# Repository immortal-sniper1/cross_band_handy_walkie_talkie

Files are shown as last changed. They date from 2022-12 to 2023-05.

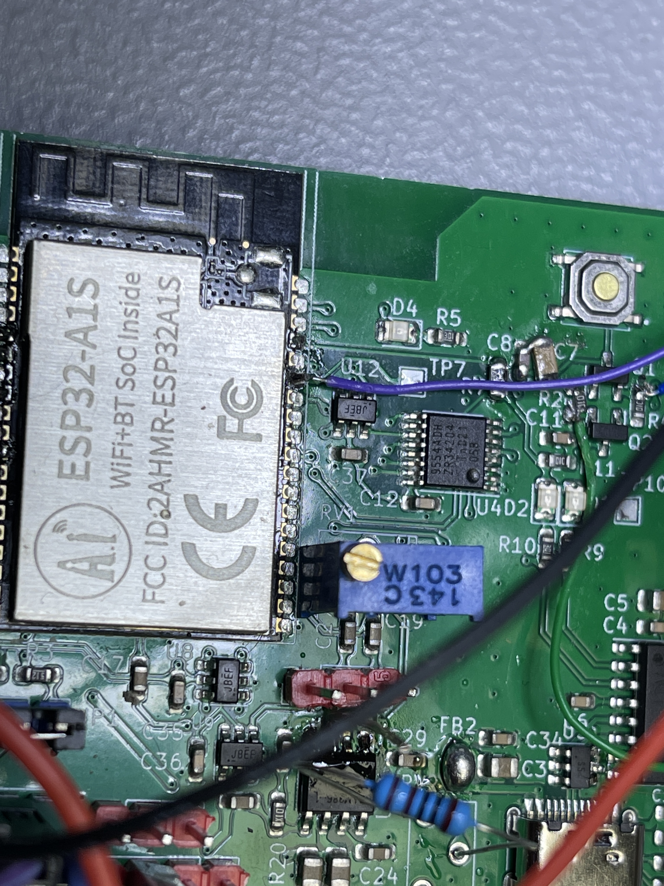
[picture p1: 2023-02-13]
Hardware/PICS/IMG_79081.JPG

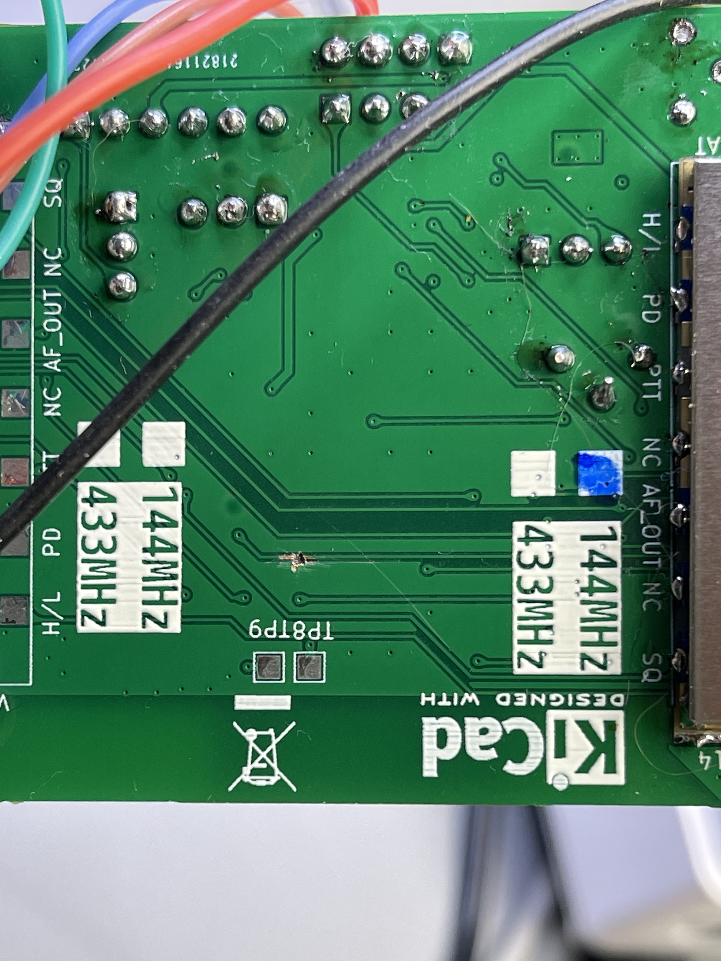
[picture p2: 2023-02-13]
Hardware/PICS/IMG_79101.JPG

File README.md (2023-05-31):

# Cross Band Handy Walkie Talkie

A Cross band handy walkie talkie: This HT would include 2 SA818s, one for 70cm and one for 2m and could be used for satellite work.
 
We recommend to install the following libraries:

__Audio__

- https://github.com/pschatzmann/arduino-audio-tools.git
- https://github.com/pschatzmann/arduino-audiokit.git (ES8388 driver for AudioKitStream class)
- https://github.com/thaaraak/es8388 (alternative ES8388 driver)
 
__DRA818__

To use the Transceiver you need an Arduino library. e.g.
- https://github.com/fatpat/arduino-dra818.git

 You can install this project as Arduino Library. To compile a Sketch select the __ESP32S3 Dev Module__ as board.

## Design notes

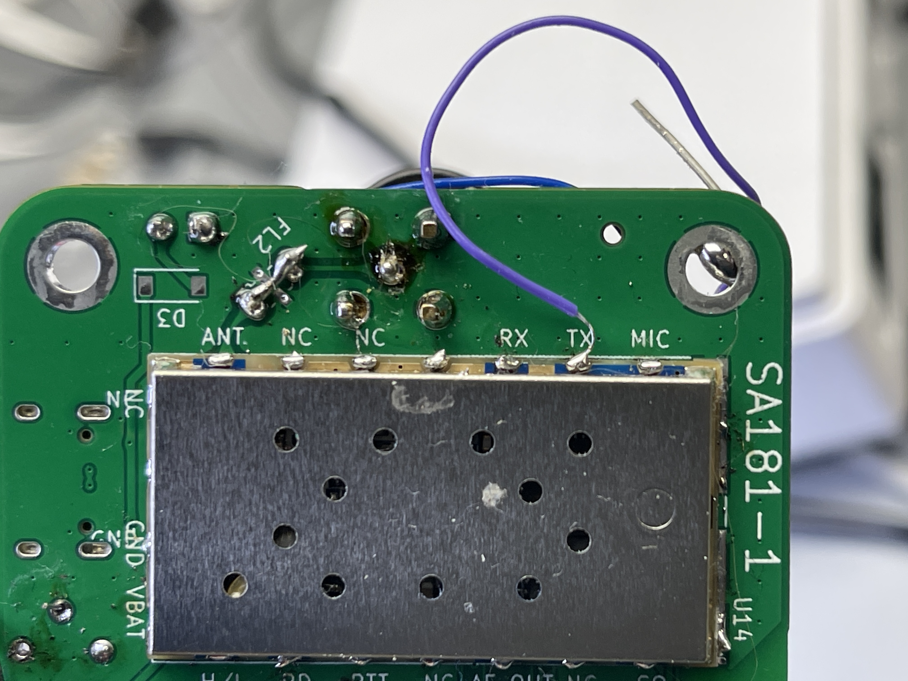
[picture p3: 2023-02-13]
Hardware/PICS/IMG_79091s.JPG

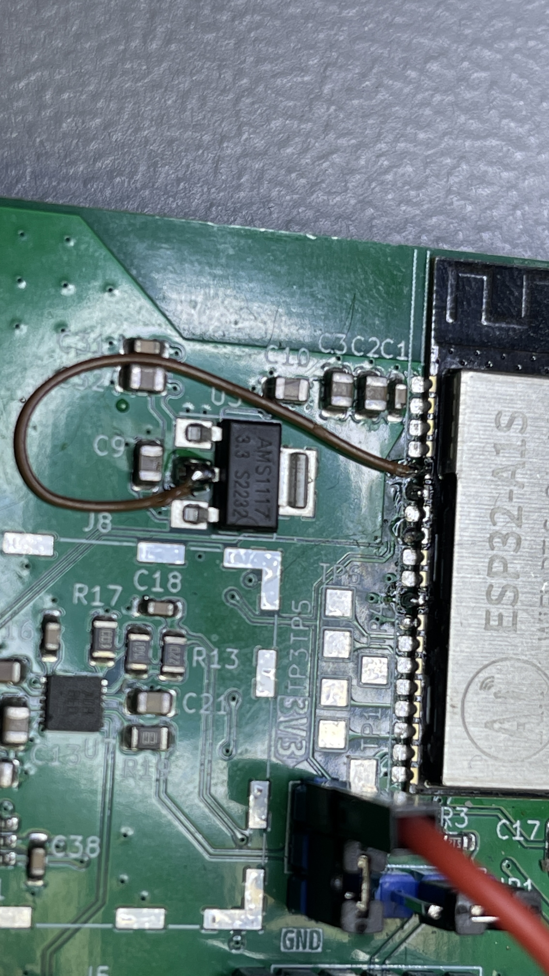
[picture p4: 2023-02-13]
Hardware/PICS/IMG_E79071.JPG

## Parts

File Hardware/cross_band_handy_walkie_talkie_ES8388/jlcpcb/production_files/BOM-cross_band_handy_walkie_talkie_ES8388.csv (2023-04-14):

Comment | Designator | Footprint | LCSC
FerriteBead_Small | FB1 | R_0805_2012Metric | C1015
AudioJack4_SwitchTR1 | J6 | PJ-316A-6A | C128987
100n | C1,C2 | C_0603_1608Metric_Pad1.08x0.95mm_HandSolder | C14663
AO3401A | Q2,Q3,Q4 | SOT-23 | C15127
4n7 | C27,C32 | C_0402_1005Metric | C1538
1u | C48,C55,C56,C8 | C_0603_1608Metric_Pad1.08x0.95mm_HandSolder | C15849
15p | C6 | C_0603_1608Metric_Pad1.08x0.95mm_HandSolder | C1644
1k | R15,R4,R5 | R_0805_2012Metric | C17513
1k | R38,R39,R44,R45 | R_0603_1608Metric | C21190
D_Schottky | D3 | D_SMA_Handsoldering | C22452
red | D4,D6,D7,D8 | LED_0603_1608Metric | C2286
1Meg | R7 | R_0603_1608Metric_Pad0.98x0.95mm_HandSolder | C22935
green | D1,D2,D5 | LED_0805_2012Metric | C2297
10 | R10,R11,R12,R13,R21,R24,R25,R47,R48,R49,R50,R8,R9 | R_0402_1005Metric | C25077
27 | R26,R27,R28,R29 | R_0402_1005Metric | C25092
0R1 | R16,R43 | R_1206_3216Metric | C25334
10k | R14,R17,R18,R19,R20,R36,R40,R46,R52,R53 | R_0402_1005Metric | C25744
10k | R1,R30,R31,R37,R42,R51,R6 | R_0603_1608Metric_Pad0.98x0.95mm_HandSolder | C25804
2k2 | R32,R33,R34,R35,R41 | R_0402_1005Metric | C25879
5k1 | R2,R22,R23,R3 | R_0402_1005Metric | C25905
SA818S | U7,U8 | SA818S | C3001549
MCU_RESET | SW1,SW2 | PTS526SK15SMTR2LFS | C318884
USB_C_Receptacle | J1 | USB_C_Receptacle_HRO_TYPE-C-31-M-12 | C319148
10k | RV1,RV2,RV3,RV4 | Potentiometer_Bourns_3314J_Vertical | C36376
ES8388 | U5 | QFN-28-1EP_4x4mm_P0.45mm_EP2.4x2.4mm_ThermalVias | C365736
22u | C24,C26,C28,C30,C33,C36,C63 | C_0805_2012Metric | C45783
TP5000 | U4 | QFN-16-1EP_4x4mm_P0.65mm_EP2.5x2.5mm_ThermalVias | C51699
1u | C13,C17,C20,C23,C34,C35,C37,C38,C40,C42,C43,C45,C46,C5,C51,C53 | C_0402_1005Metric | C52923
Micro_SD_Card_Det | J2 | microSD_HC_Molex_104031-0811 | C585350
4u7 | L1,L2,L3,L4 | Inductor_2.5x2x1.2mm | C602016
AMS1117-3.3 | U3 | SOT-223-3_TabPin2 | C6186
TPA2012D2 | U6 | QFN-20-1EP_4x4mm_P0.5mm_EP2.6x2.6mm_ThermalVias | C7717
SRV05-4 | U1 | SOT-23-6 | C85364
nMOS | Q1,Q5,Q6 | SOT-23 | C8545
10u | C10,C11,C12,C14,C15,C16,C18,C19,C21,C22,C25,C29,C3,C31,C39,C4,C41,C44,C47,C50,C52,C54,C57,C58,C59,C60,C61,C62,C7,C9 | C_0603_1608Metric | C96446
Screw_Terminal_01x02 | J5 | Altech_AK300_1x02_P5.00mm_45-Degree
SMA | J7 | SMA_Amphenol_901-144_Vertical
SMA | J8 | SMA_Amphenol_901-144_Vertical
Screw_Terminal_01x02 | J3 | Altech_AK300_1x02_P5.00mm_45-Degree
LFCN-160 | FL2 | Filter_Mini-Circuits_FV1206
LFCN-160 | FL1 | Filter_Mini-Circuits_FV1206

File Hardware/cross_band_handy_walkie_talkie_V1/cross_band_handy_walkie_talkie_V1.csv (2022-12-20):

Id | Designator | Package | Quantity | Designation | Supplier and ref
1 | J5,J3,J2,J4 | PinHeader_1x03_P2.54mm_Vertical | 4 | Conn_01x03
2 | C7 | C_0603_1608Metric_Pad1.08x0.95mm_HandSolder | 1 | DNP
3 | C10,C3,C5,C33,C32,C2,C26,C13,C14,C9,C25 | C_0805_2012Metric | 11 | 10u
4 | RV1,RV2 | Potentiometer_Bourns_3266W_Vertical | 2 | 10k
5 | R2,R4,R11 | R_0603_1608Metric_Pad0.98x0.95mm_HandSolder | 3 | 10k
6 | C29 | C_0603_1608Metric_Pad1.08x0.95mm_HandSolder | 1 | 1u-10u?
7 | C28,C20,C27,C19,C17,C24 | C_0603_1608Metric_Pad1.08x0.95mm_HandSolder | 6 | 1u
8 | R10,R9,R5 | R_0603_1608Metric_Pad0.98x0.95mm_HandSolder | 3 | 300
9 | C4,C38,C6,C18,C11,C12,C16,C34,C31,C1,C37,C35,C36 | C_0603_1608Metric_Pad1.08x0.95mm_HandSolder | 13 | 100n
10 | U11,U8,U9,U12 | SOT-23-6 | 4 | TS5A63157DBV
11 | J7 | PinHeader_1x04_P2.54mm_Vertical | 1 | Conn_01x04
12 | D4,D1,D2 | LED_0805_2012Metric | 3 | LED_Small
13 | R1,R3,R14,R12 | R_0603_1608Metric_Pad0.98x0.95mm_HandSolder | 4 | 5k1
14 | U4 | TSSOP-16_4.4x5mm_P0.65mm | 1 | PCA9554APW
15 | SW1 | PTS526SK15SMTR2LFS | 1 | MCU_RESET
16 | R20 | R_0603_1608Metric_Pad0.98x0.95mm_HandSolder | 1 | 10
17 | U2 | ESP32-A1S | 1 | ESP32-A1S
18 | U3 | SOT-223-3_TabPin2 | 1 | AMS1117-3.3
19 | R17 | R_0805_2012Metric | 1 | 100k
20 | J15,J14 | SMA_Amphenol_901-144_Vertical | 2 | SMA
21 | C21 | C_0805_2012Metric | 1 | 470n
22 | Q1,Q2 | SOT-23 | 2 | MMBT3904
23 | C30 | C_0603_1608Metric_Pad1.08x0.95mm_HandSolder | 1 | 47n
24 | U10 | SOIC-8-1EP_3.9x4.9mm_P1.27mm_EP2.41x3.3mm_ThermalVias | 1 | LM386
25 | R15 | R_0805_2012Metric | 1 | 150k
26 | C15 | C_0603_1608Metric_Pad1.08x0.95mm_HandSolder | 1 | 10p
27 | C22 | C_0805_2012Metric | 1 | 2u2
28 | L1 | L_0805_2012Metric | 1 | L_Small
29 | J1 | PinHeader_1x06_P2.54mm_Vertical | 1 | Conn_01x06
30 | U1 | SOIC-16_3.9x9.9mm_P1.27mm | 1 | CH340C
31 | JP1 | PinHeader_1x03_P2.54mm_Vertical | 1 | Jumper_3_Bridged12
32 | R19 | R_0805_2012Metric | 1 | 1k
33 | FB2 | R_0805_2012Metric_Pad1.20x1.40mm_HandSolder | 1 | MH2029-401Y
34 | J9 | PinHeader_1x02_P2.54mm_Vertical | 1 | Conn_01x02
35 | R16,R7 | R_0603_1608Metric_Pad0.98x0.95mm_HandSolder | 2 | 1Meg
36 | C8 | C_0603_1608Metric_Pad1.08x0.95mm_HandSolder | 1 | 15n
37 | R13 | R_0805_2012Metric | 1 | 2k2
38 | J6 | USB_C_Receptacle_HRO_TYPE-C-31-M-12 | 1 | USB_C_Receptacle
39 | U7 | DFN-14-1EP_3x3mm_P0.4mm_EP1.78x2.35mm | 1 | MAX9814
40 | FL2,FL1 | Filter_Mini-Circuits_FV1206 | 2 | LFCN-160
41 | D3 | D_SOD-123 | 1 | D_Small
42 | U14,U13 | SA818S | 2 | SA818S

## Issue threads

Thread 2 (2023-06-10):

Status

pschatzmann, 2023-06-10:
Since you did not open the discussion tab, I create an issue instead to document the current status:

All my test cases were passing except the audio input via the earphones which has a lot of noise
- output
- output via amplifier
- SD
- SDMMC

On my board I do not have the SA818s soldered so I can't really do any tests with this. But just for the documentation could you describe how the output and input is connected to the ES8388: I would assume that they are on AUDIO_HAL_ADC_INPUT_LINE2 and AUDIO_HAL_DAC_OUTPUT_LINE2 ?

immortal-sniper1, 2023-06-10:
1 i dont know how do open discussions
2 regarding noise i am not sure and we need to talk with Andreas , maybe another cap type heavier via stitching or a pre amplifier for larger input impedance .
3 Yes they are supposed to be connected there. The modules can receive analogue audio and output it too and there are a few pins that control this functionality
As a note on the modules even if we had them it would be only a receiver or a sender so in a way the RF tests need to be done by Andreas since he has most boards and can also ask x y z for a transmission on those bands. Theoretically we can also receive audio but it is going to be more like catch what u can.

pschatzmann, 2023-06-10:
Activating discussions is easy: Just click on the settings tab and activate the Discussions flag

immortal-sniper1, 2023-06-10:
try now , should be open.
BTW was the speed for the SPI and the codec appropriate ?
did u use SPI 1bit or 4bit for the SD card ?

pschatzmann, 2023-06-10:
If I remember right, SDMMC was working only with 4 bits but not with 1 bit. At least that't the version that you find in the [example](https://github.com/immortal-sniper1/cross_band_handy_walkie_talkie/blob/master/examples/test-sdmmc/test-sdmmc.ino)

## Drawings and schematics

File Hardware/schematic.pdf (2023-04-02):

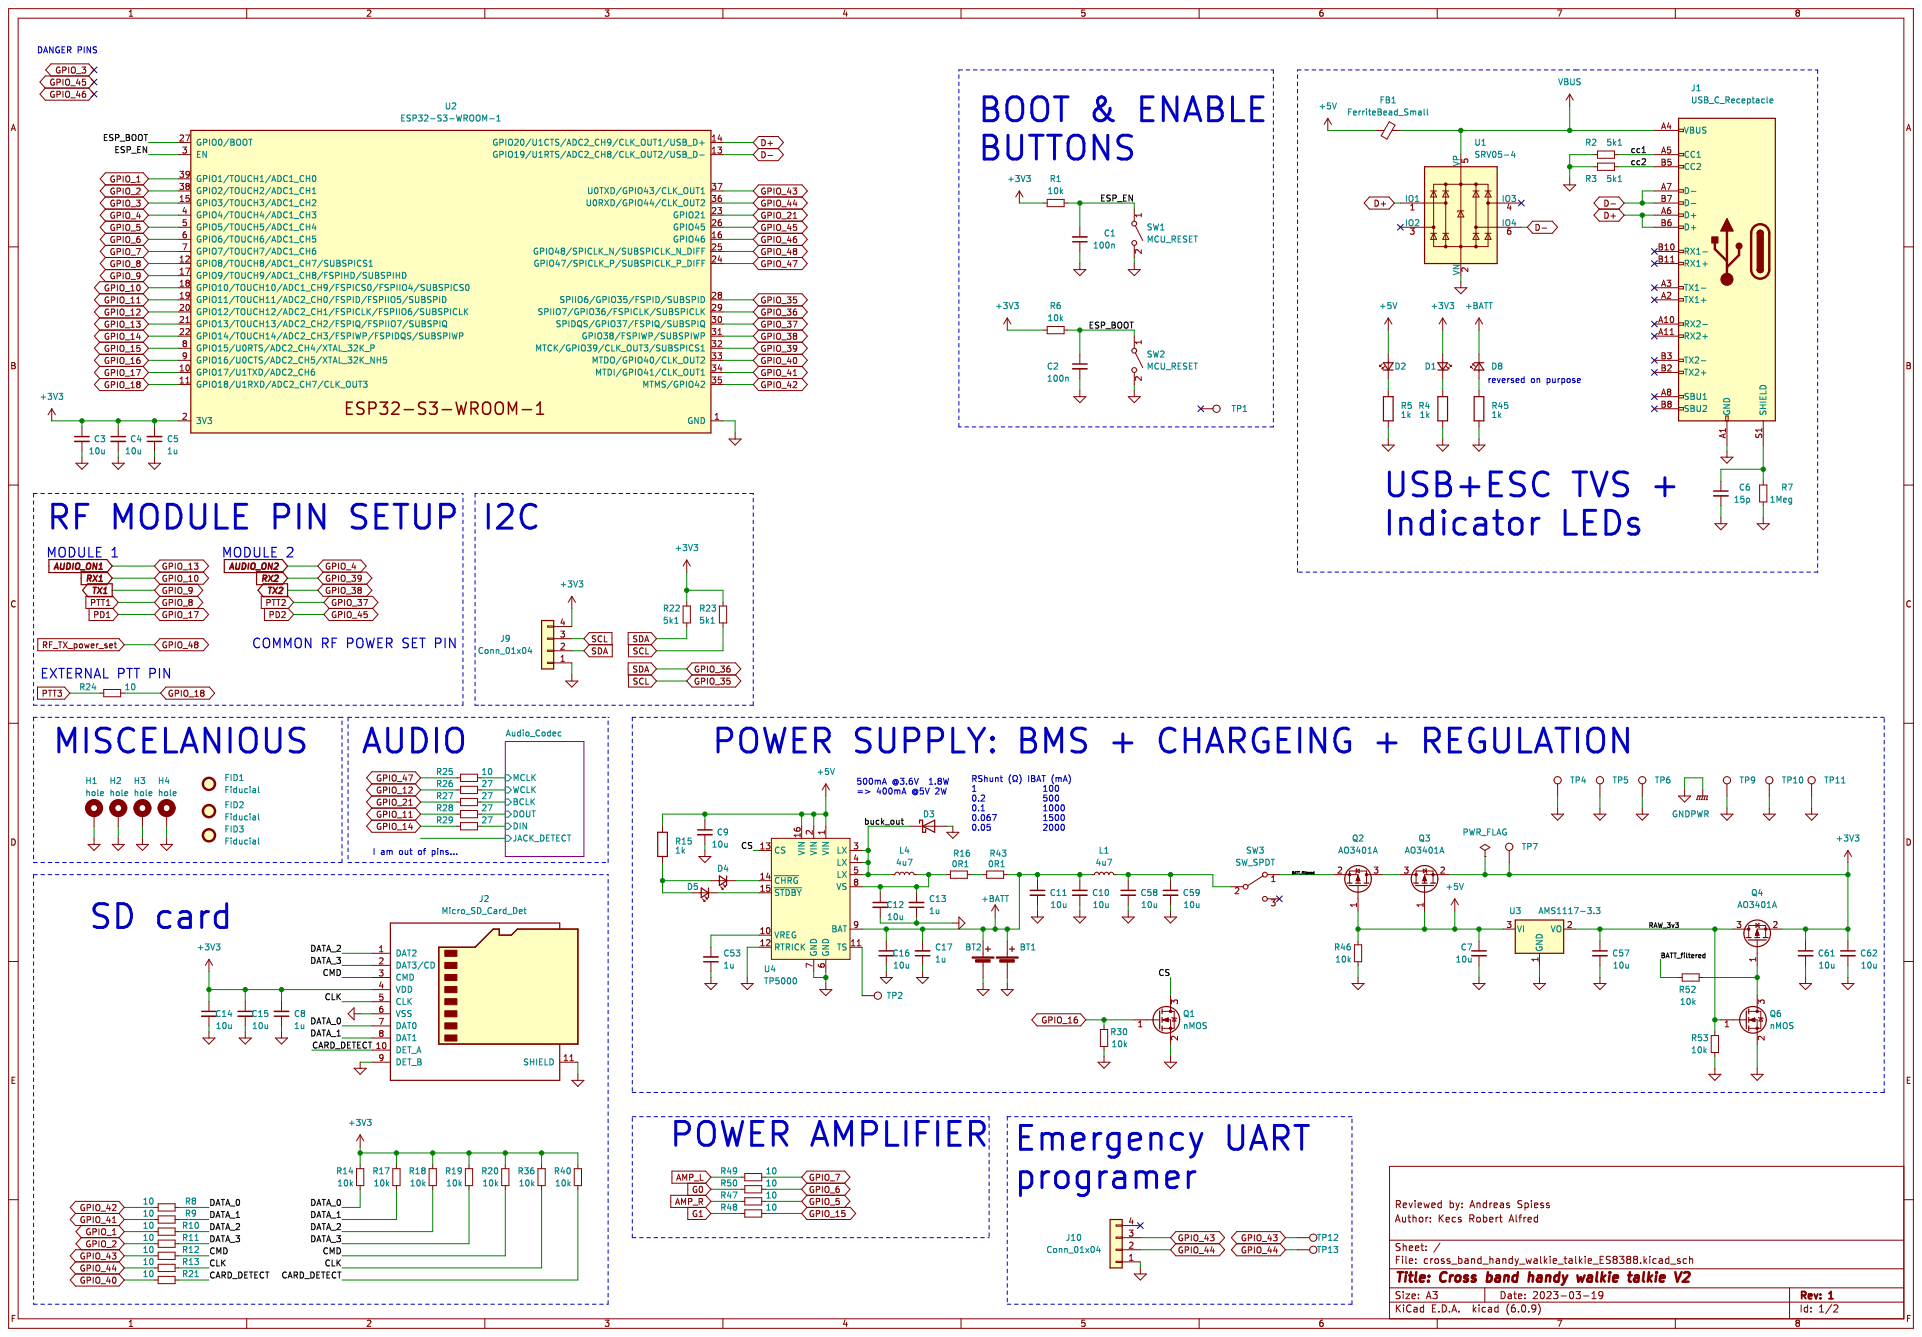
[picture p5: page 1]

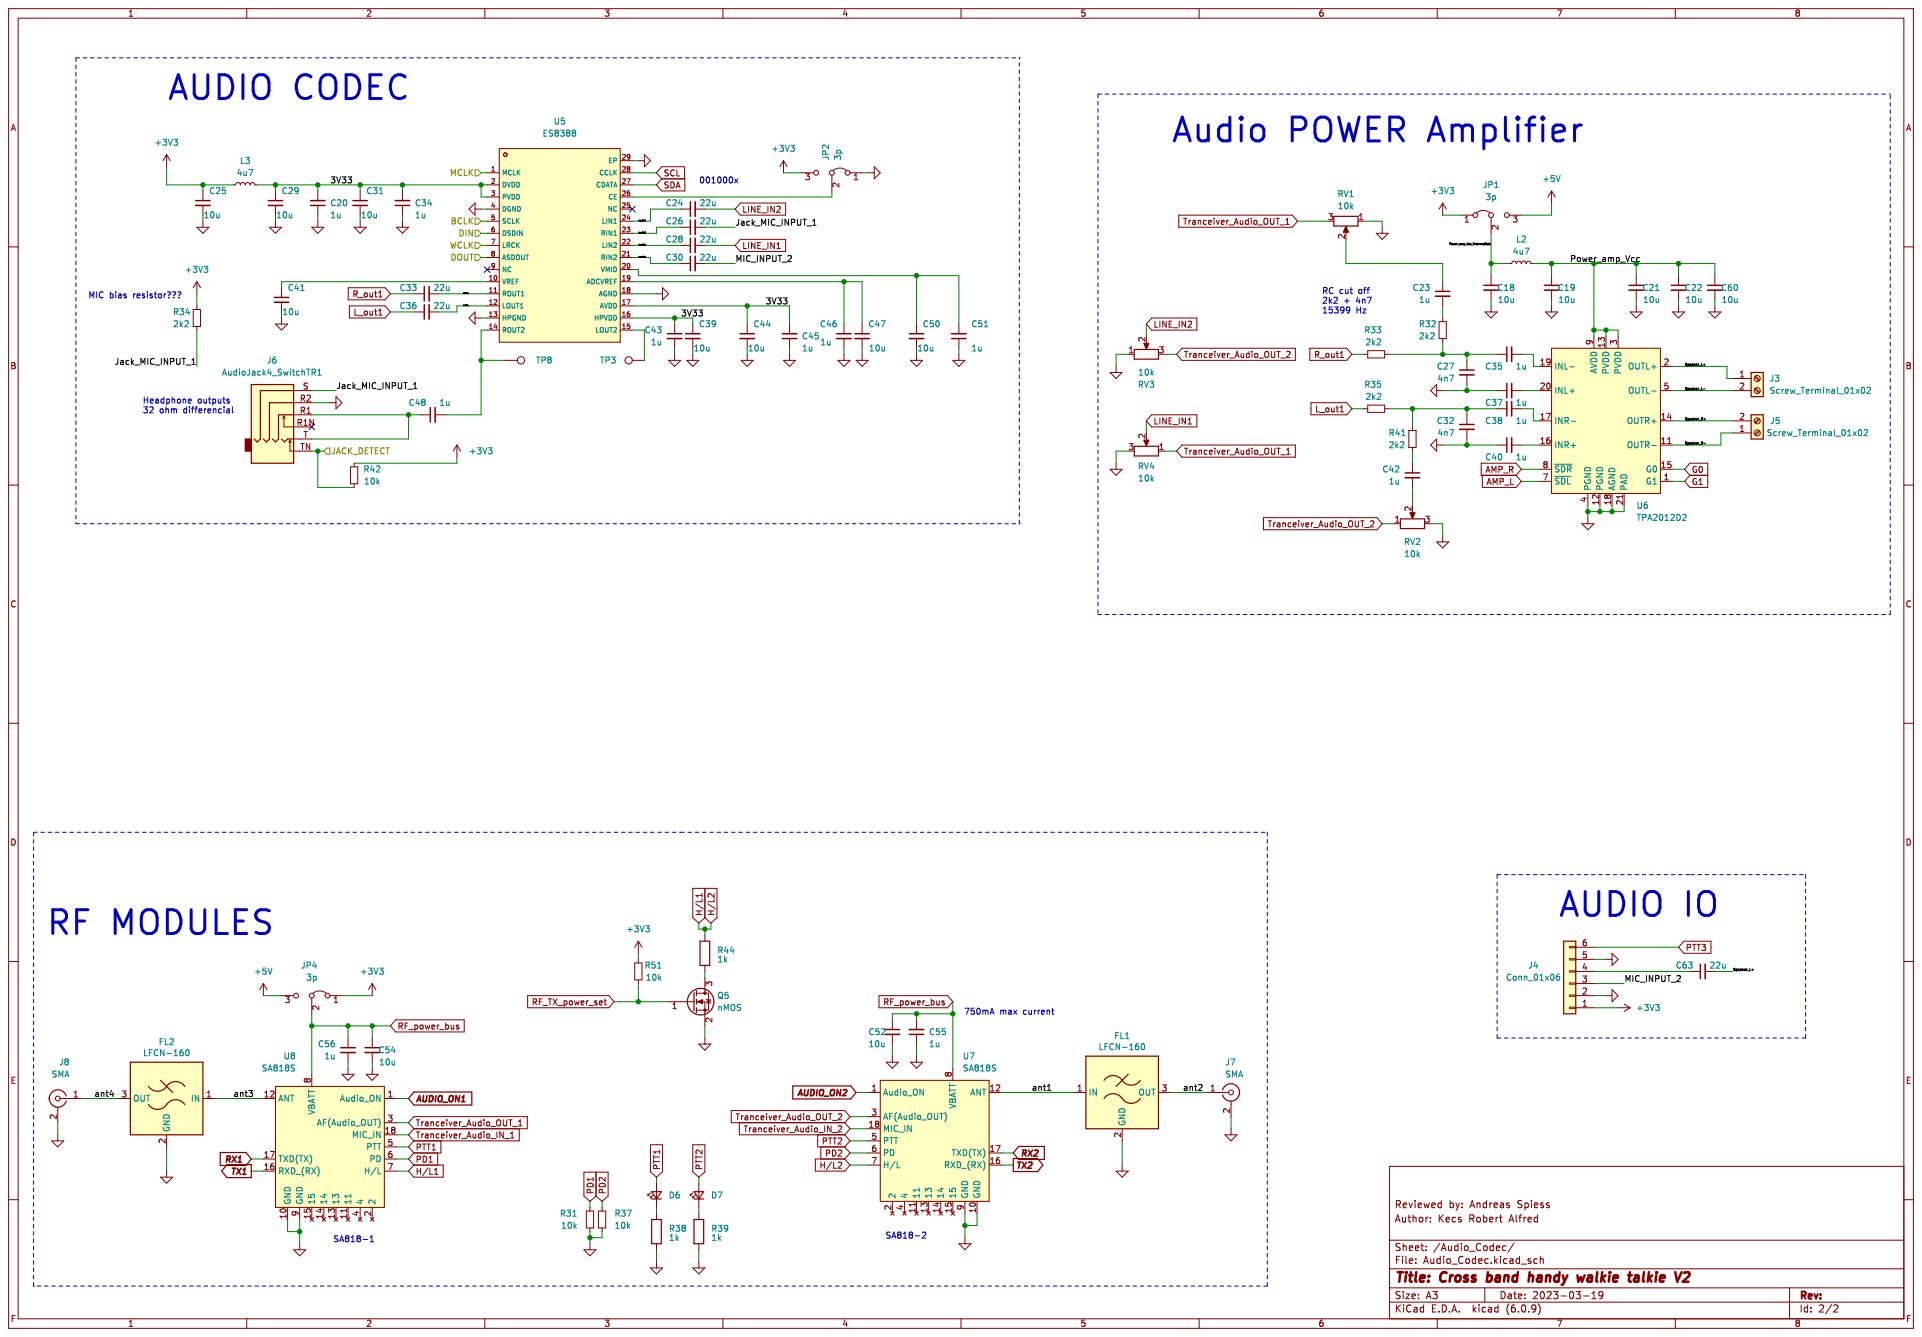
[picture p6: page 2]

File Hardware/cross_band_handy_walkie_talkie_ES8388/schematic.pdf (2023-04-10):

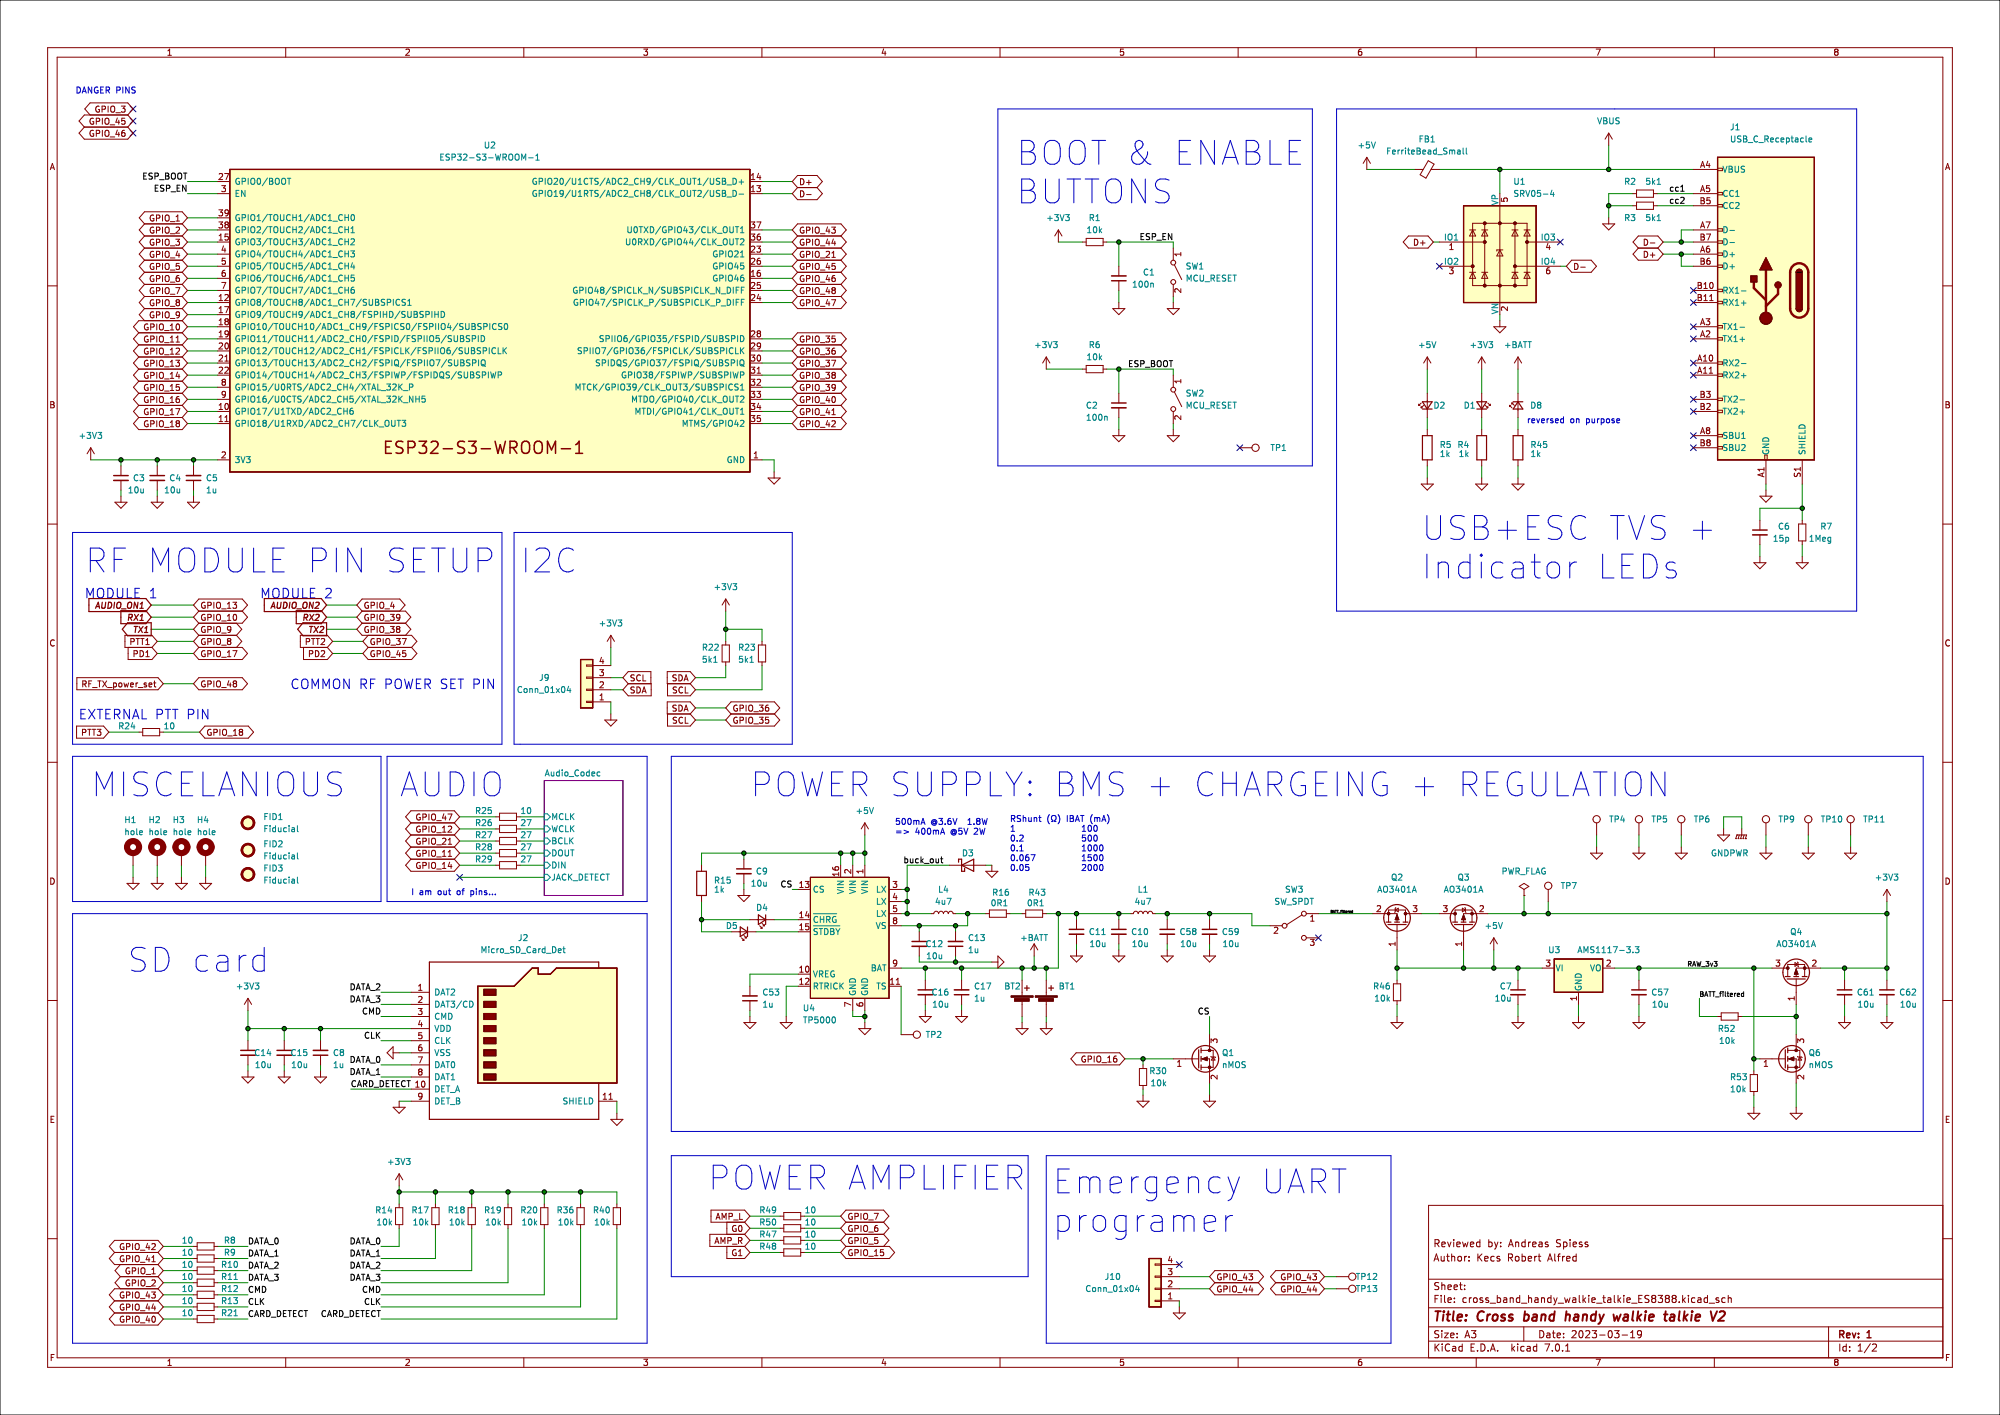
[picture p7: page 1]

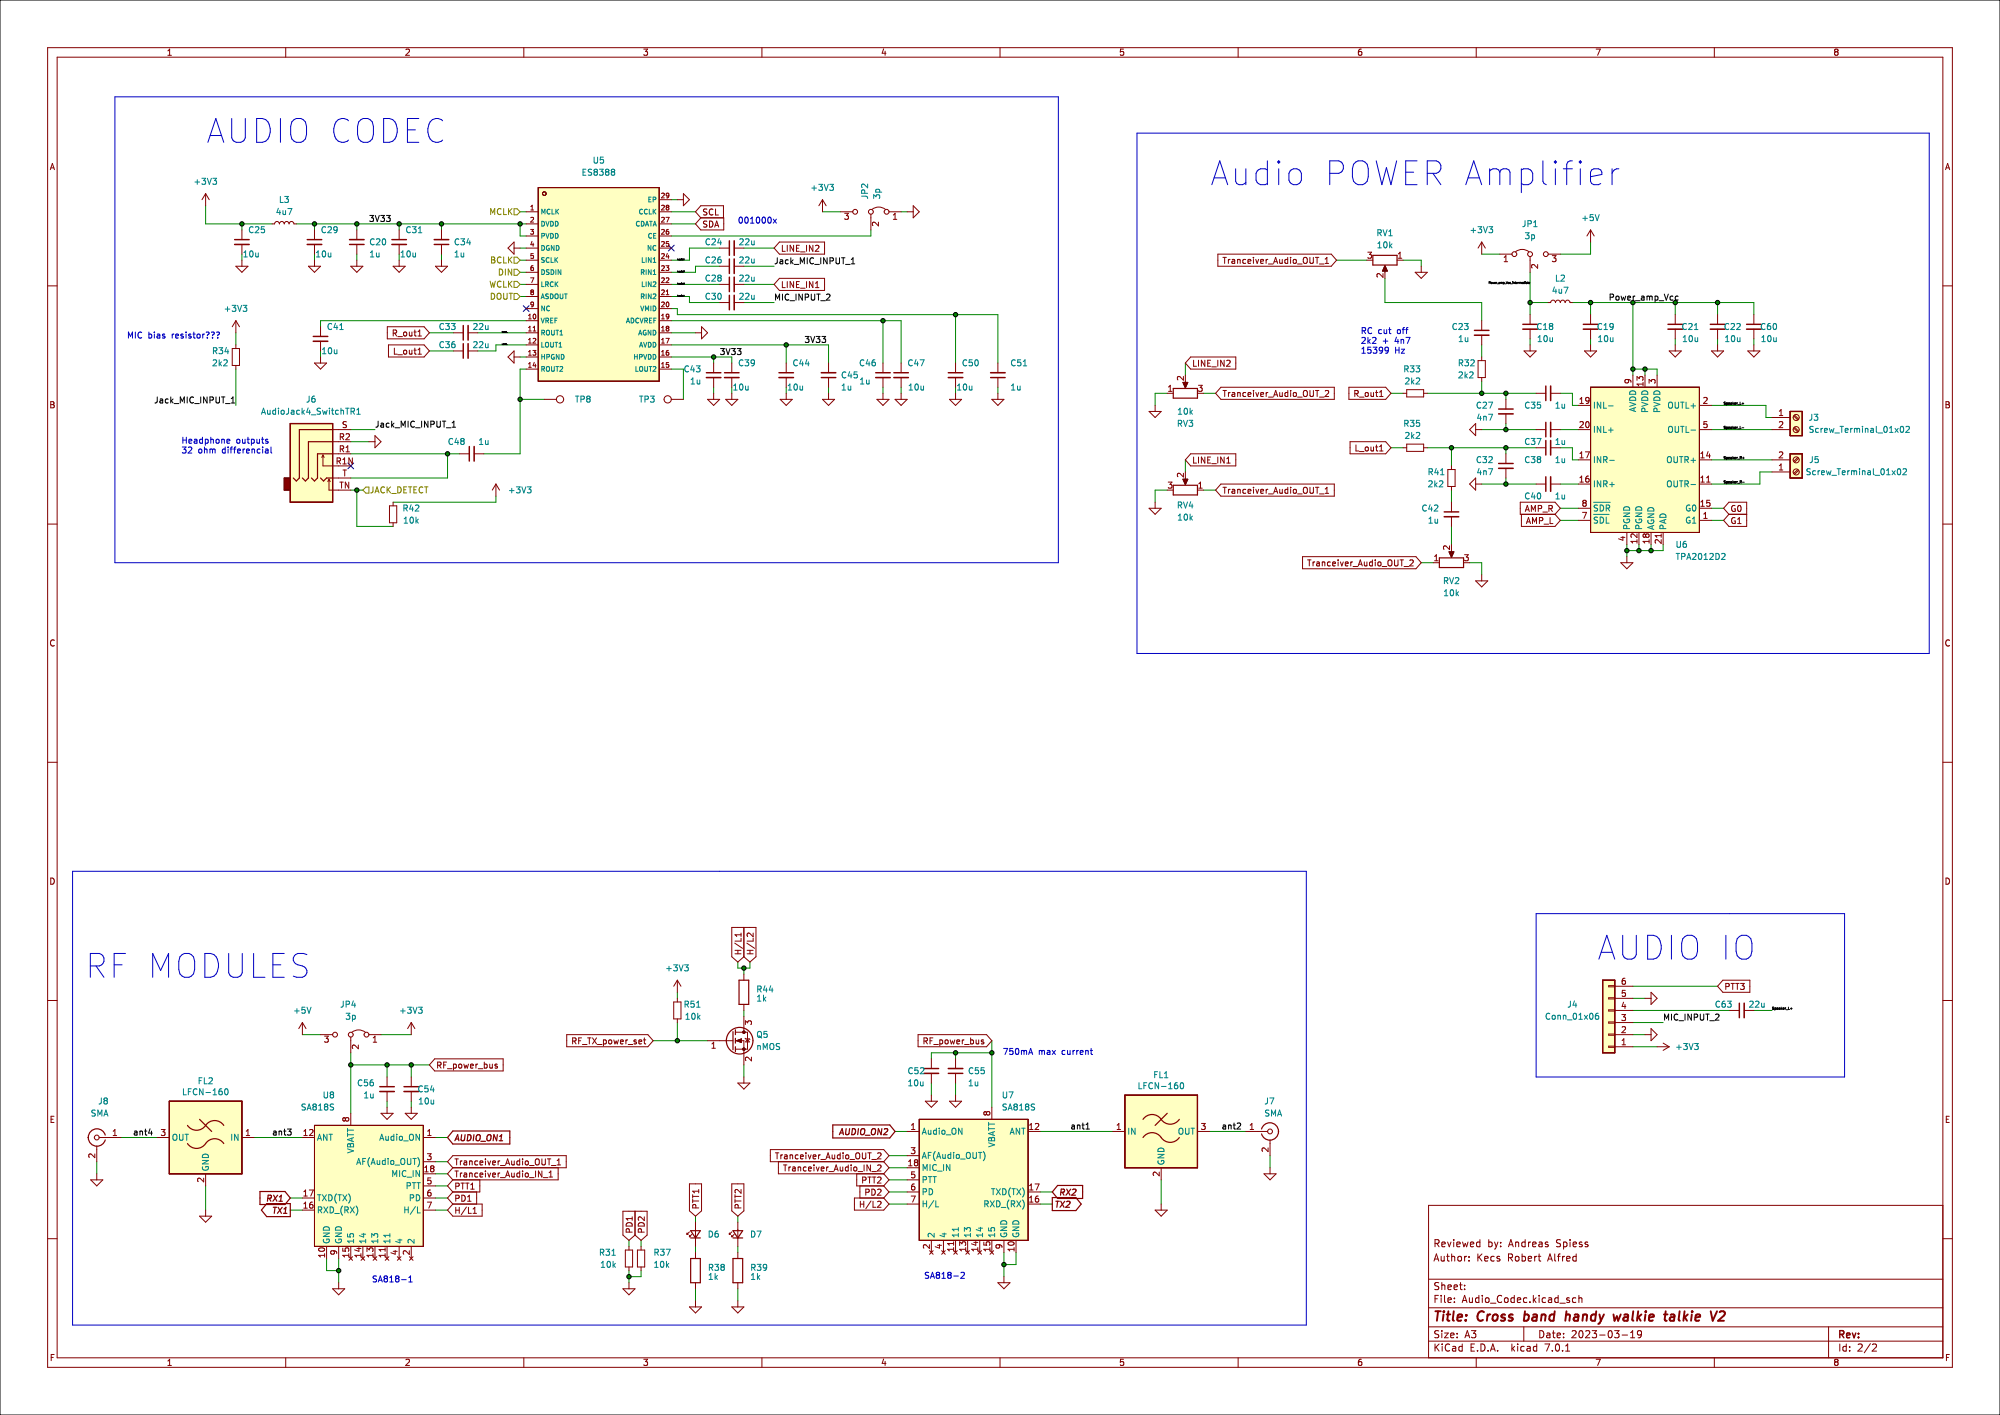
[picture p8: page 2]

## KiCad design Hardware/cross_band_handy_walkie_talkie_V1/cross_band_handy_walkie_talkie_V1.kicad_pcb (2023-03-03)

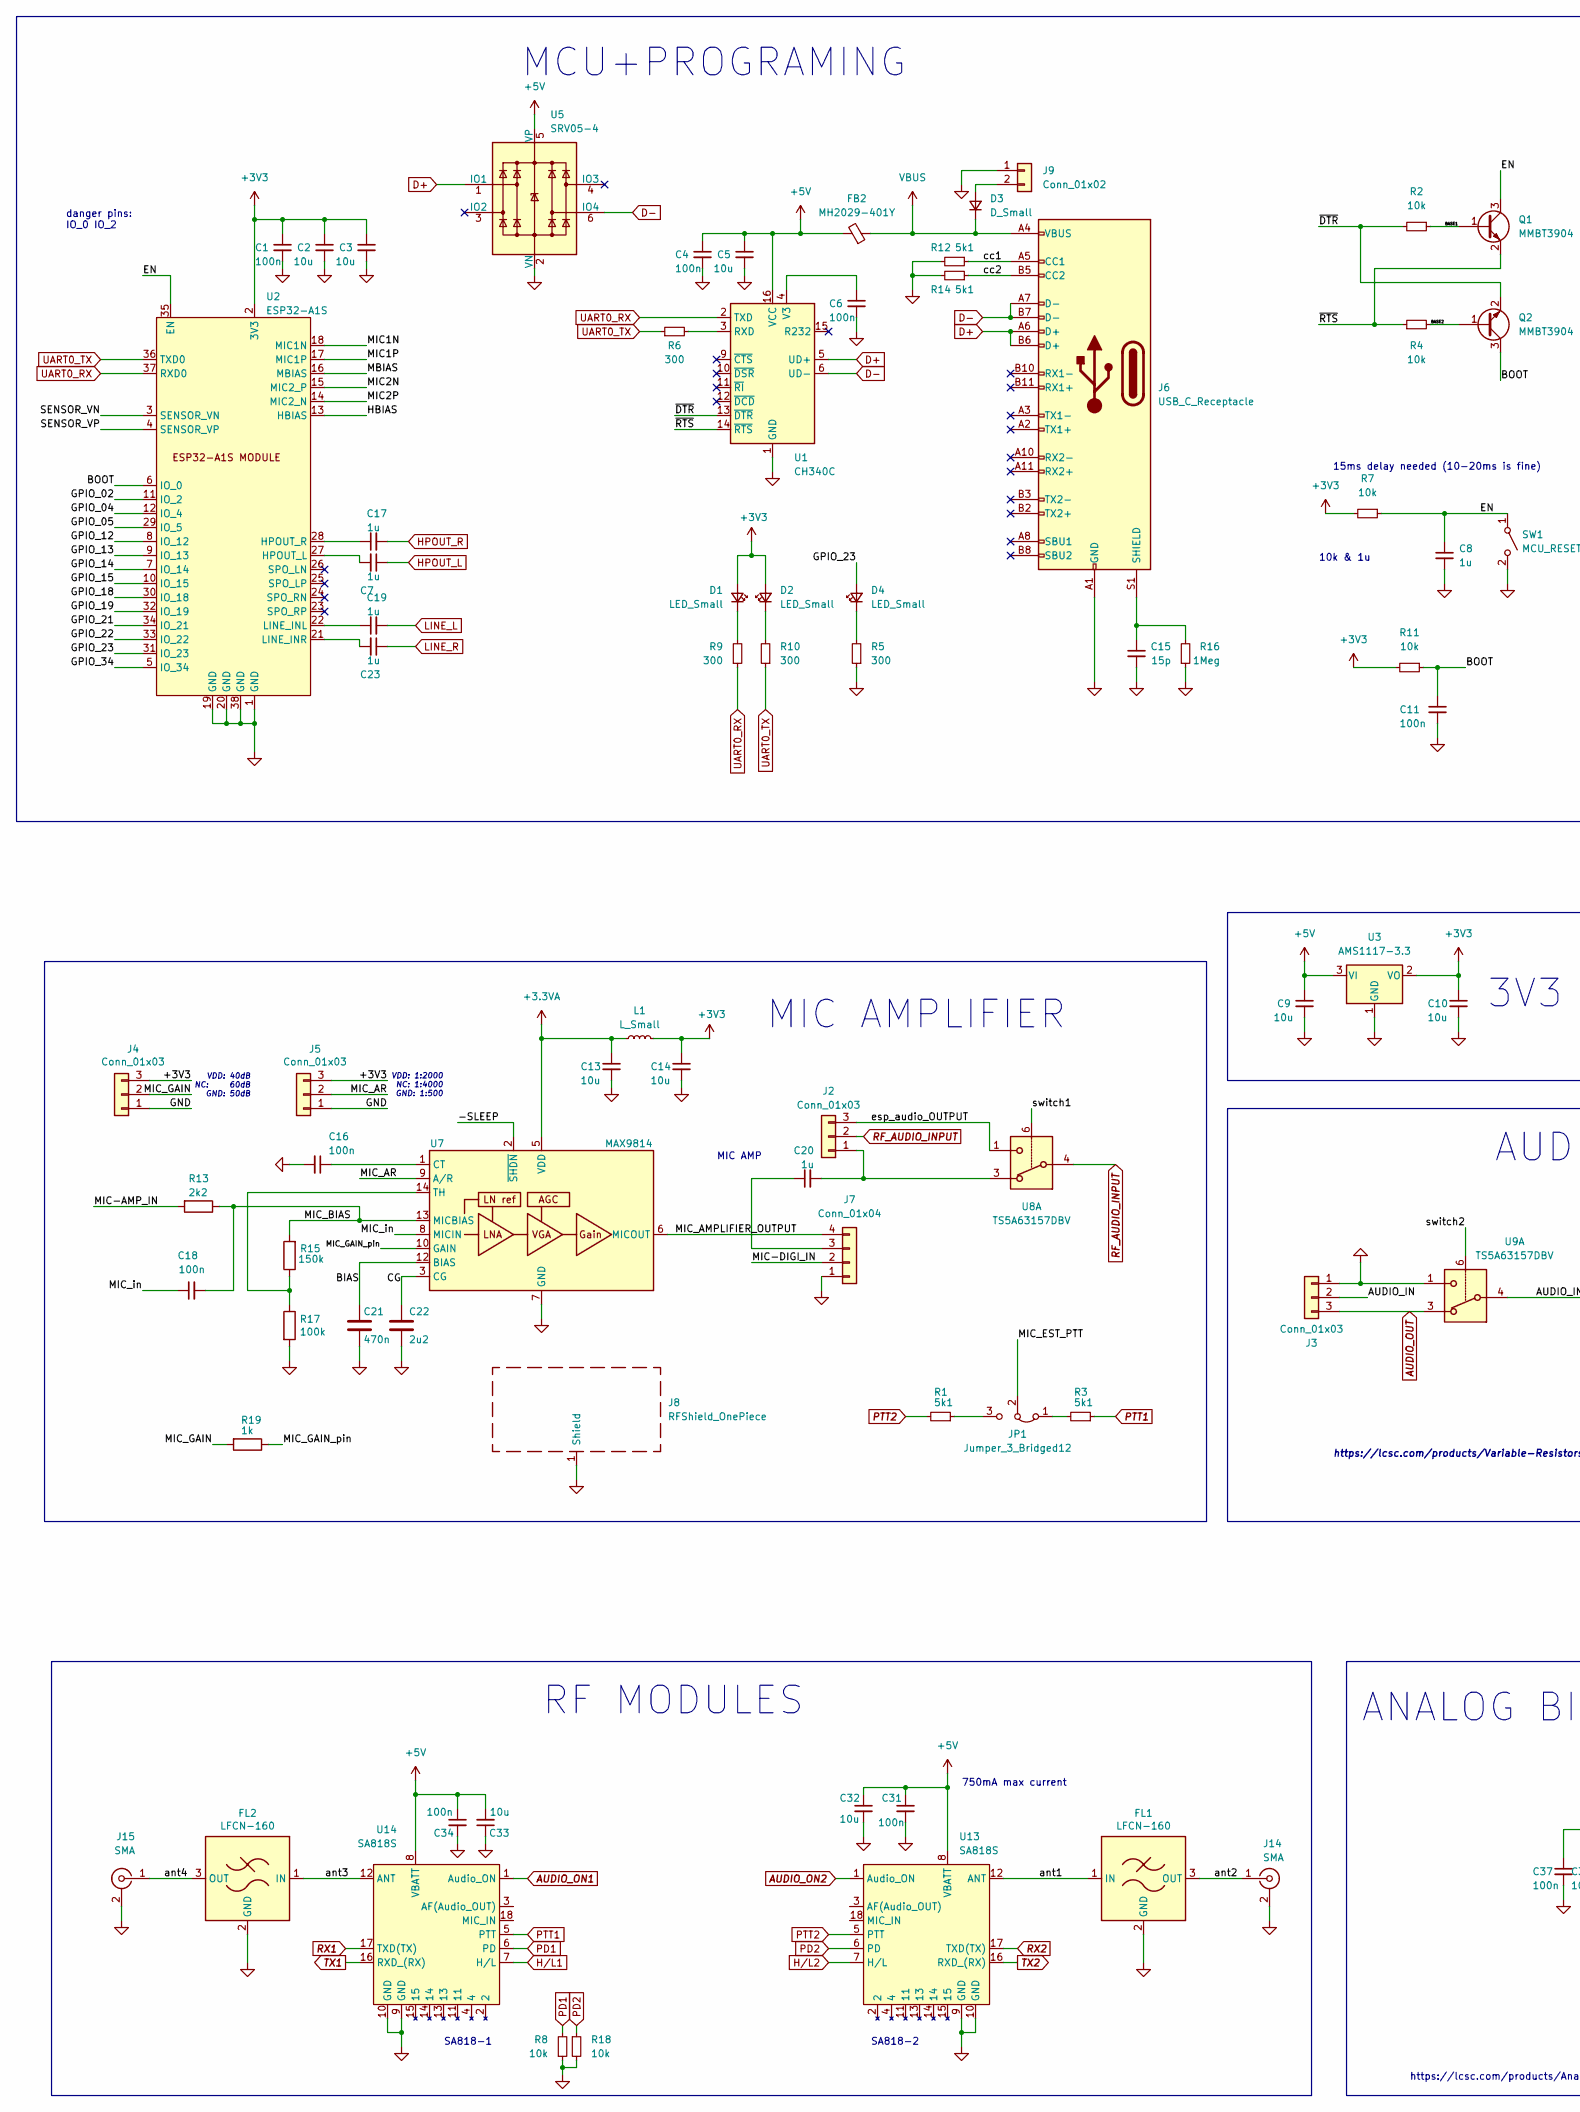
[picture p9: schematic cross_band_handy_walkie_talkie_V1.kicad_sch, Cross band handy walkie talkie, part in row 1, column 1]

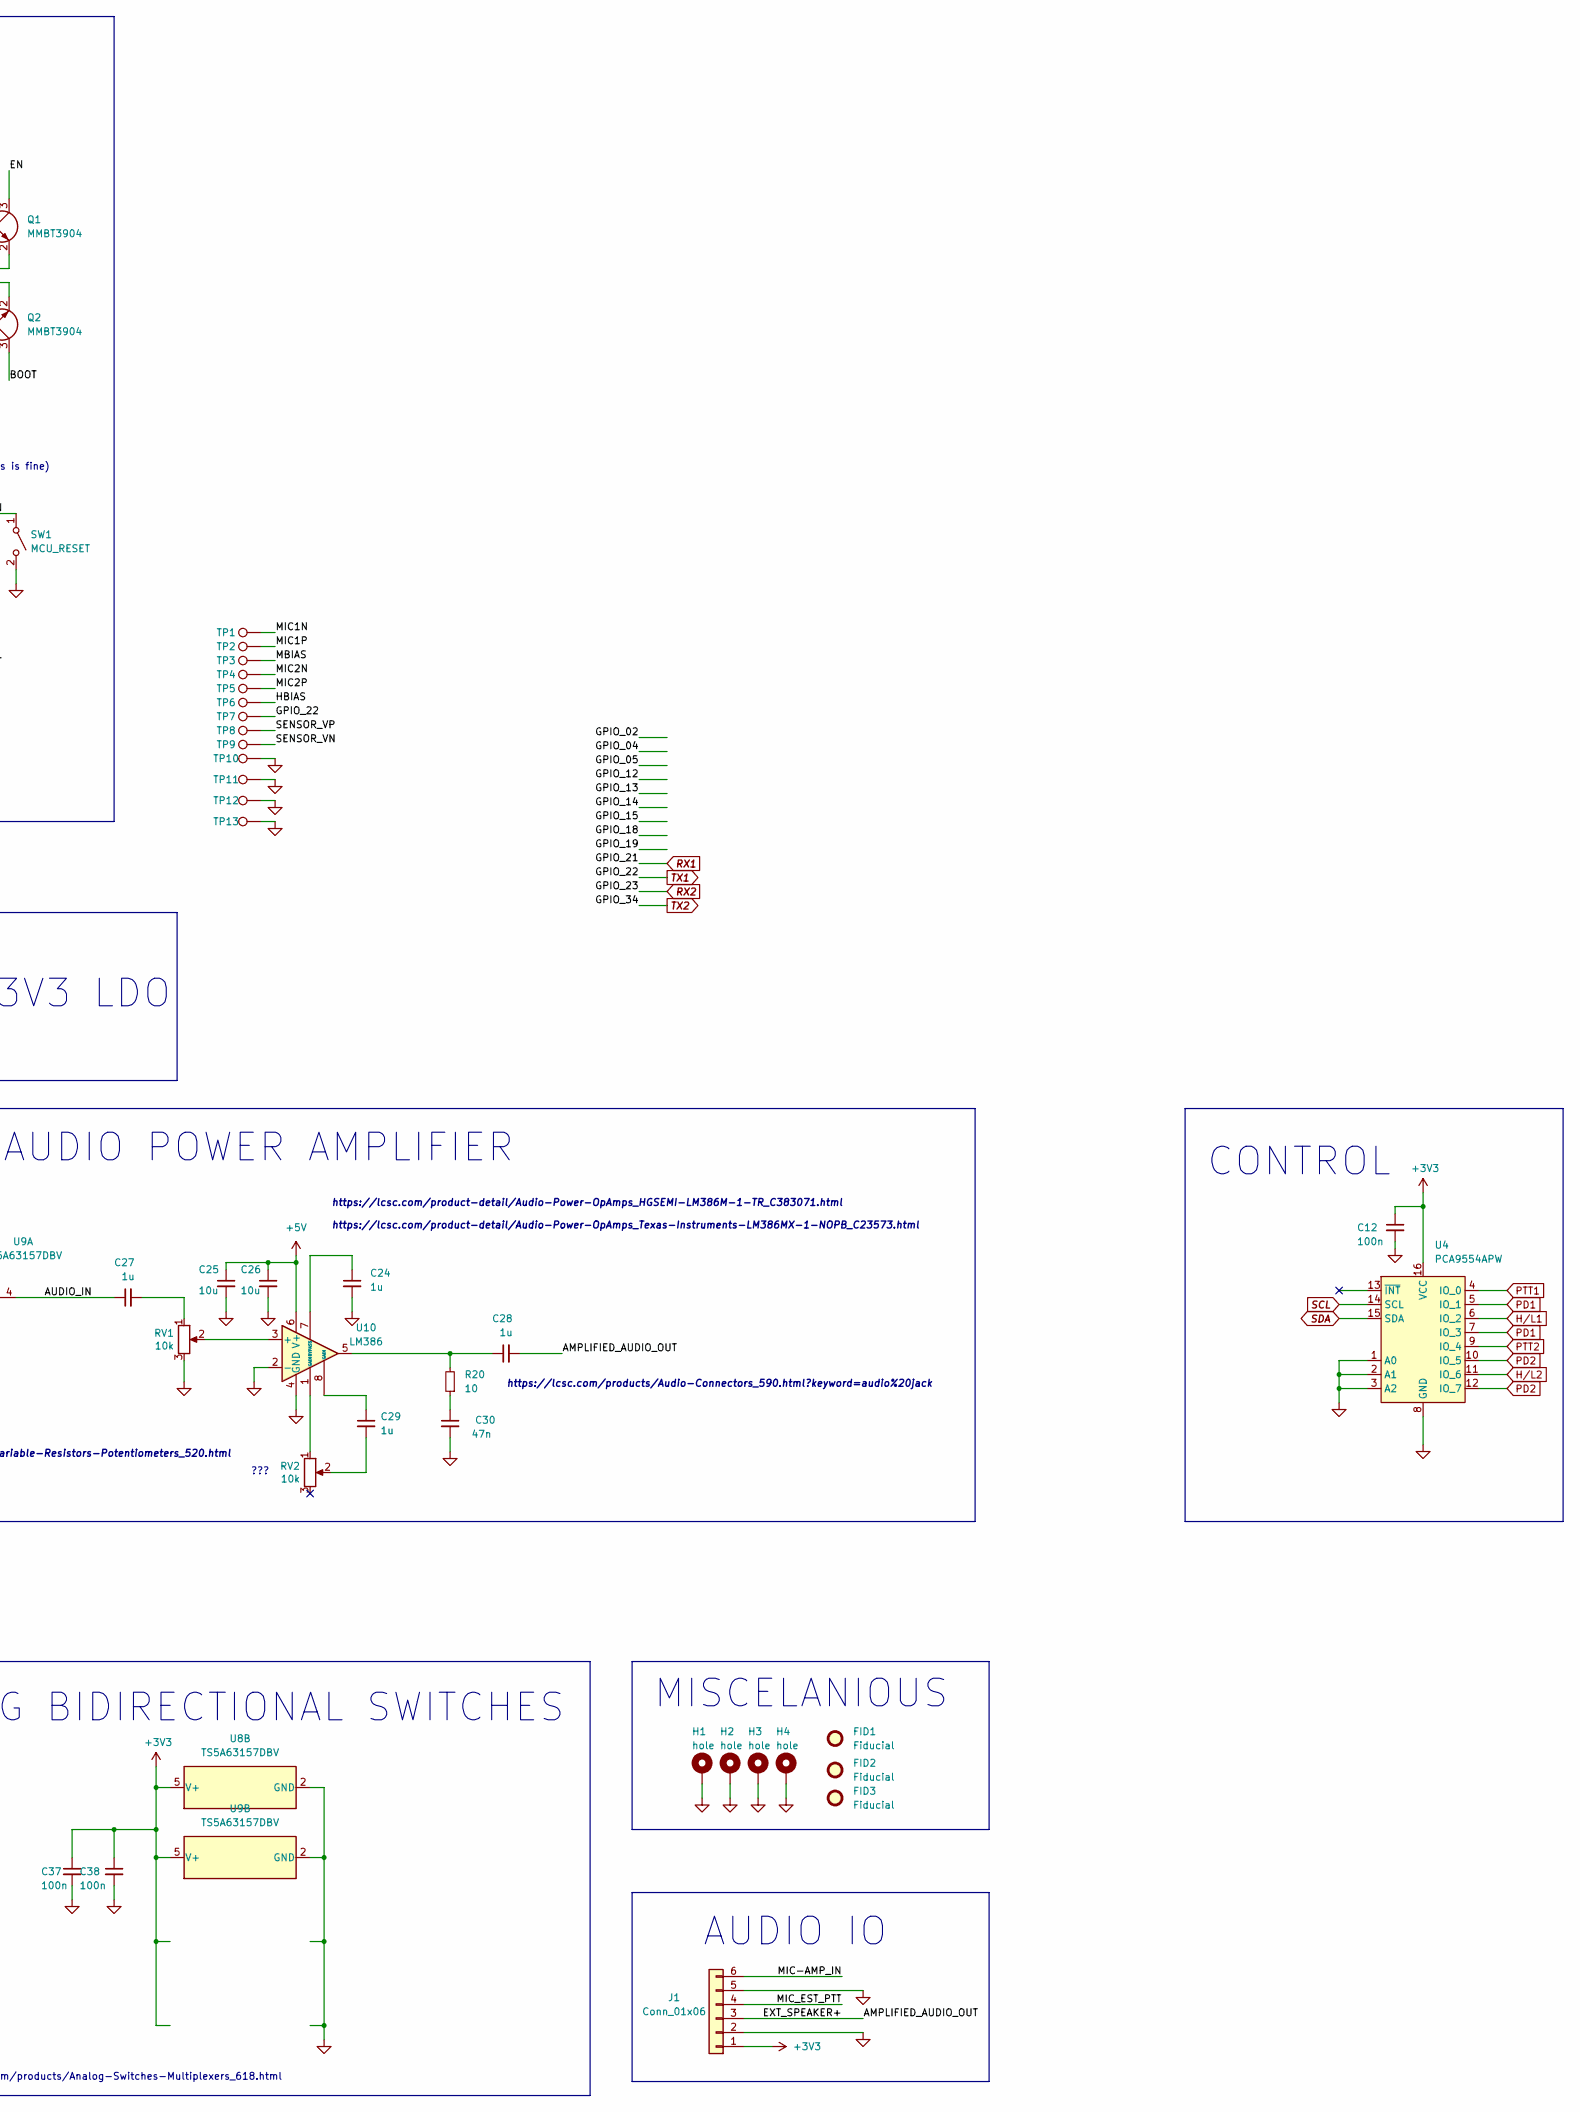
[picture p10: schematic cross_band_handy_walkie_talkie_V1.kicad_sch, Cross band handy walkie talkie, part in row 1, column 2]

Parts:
C1, C4, C6, C11, C12, C16, C18, C31, C34, C37, C38: 100n; C_0603_1608Metric_Pad1.08x0.95mm_HandSolder; LCSC C14663
C2, C3, C5, C9, C10, C13, C14, C25, C26, C32, C33: 10u; C_0805_2012Metric; LCSC C15850
C7, C8, C17, C19, C20, C23, C24, C27, C28, C29: 1u; C_0603_1608Metric_Pad1.08x0.95mm_HandSolder; LCSC C15849
C15: 15p; C_0603_1608Metric_Pad1.08x0.95mm_HandSolder; LCSC C1644
C21: 470n; C_0805_2012Metric; LCSC C13967
C22: 2u2; C_0805_2012Metric; LCSC C49217
C30: 47n; C_0603_1608Metric_Pad1.08x0.95mm_HandSolder; LCSC C1622
D1, D2, D4: LED_Small; LED_0805_2012Metric; LCSC C2297
D3: D_Small; D_SOD-123
FB2: MH2029-401Y; R_0805_2012Metric_Pad1.20x1.40mm_HandSolder
FID1: Fiducial; Fiducial_0.5mm_Mask1mm
FID2: Fiducial; KiCad-Logo2_5mm_SilkScreen
FID3: Fiducial; WEEE-Logo_4.2x6mm_SilkScreen
FL1, FL2: LFCN-160; Filter_Mini-Circuits_FV1206
H1, H2, H3, H4: hole; MountingHole_3.2mm_M3_DIN965_Pad_TopBottom
J1: Conn_01x06; PinHeader_1x06_P2.54mm_Vertical
J2, J3, J4, J5: Conn_01x03; PinHeader_1x03_P2.54mm_Vertical
J6: USB_C_Receptacle; USB_C_Receptacle_HRO_TYPE-C-31-M-12; LCSC C319148
J7: Conn_01x04; PinHeader_1x04_P2.54mm_Vertical
J8: RFShield_OnePiece; Wuerth_36103205_20x20mm
J9: Conn_01x02; PinHeader_1x02_P2.54mm_Vertical
J14, J15: SMA; SMA_Amphenol_901-144_Vertical
JP1: Jumper_3_Bridged12; PinHeader_1x03_P2.54mm_Vertical
L1: L_Small; L_0805_2012Metric; LCSC C1046
Q1, Q2: MMBT3904; SOT-23; LCSC C20526
R1, R3, R12, R14: 5k1; R_0603_1608Metric_Pad0.98x0.95mm_HandSolder; LCSC C23186
R2, R4, R7, R8, R11, R18: 10k; R_0603_1608Metric_Pad0.98x0.95mm_HandSolder; LCSC C25804
R5, R6, R9, R10: 300; R_0603_1608Metric_Pad0.98x0.95mm_HandSolder; LCSC C23025
R13: 2k2; R_0805_2012Metric; LCSC C17520
R15: 150k; R_0805_2012Metric; LCSC C17470
R16: 1Meg; R_0603_1608Metric_Pad0.98x0.95mm_HandSolder; LCSC C22935
R17: 100k; R_0805_2012Metric; LCSC C149504
R19: 1k; R_0805_2012Metric; LCSC C17513
R20: 10; R_0603_1608Metric_Pad0.98x0.95mm_HandSolder
RV1, RV2: 10k; Potentiometer_Bourns_3266W_Vertical; LCSC C118956
SW1: MCU_RESET; PTS526SK15SMTR2LFS; LCSC C318884
TP1, TP2, TP3, TP4, TP5, TP6, TP7, TP8, TP9, TP10, TP11, TP12, TP13: TestPoint; TestPoint_Pad_1.5x1.5mm
U1: CH340C; SOIC-16_3.9x9.9mm_P1.27mm; LCSC C84681
U2: ESP32-A1S; LCSC C277945
U3: AMS1117-3.3; SOT-223-3_TabPin2; LCSC C6186
U4: PCA9554APW; TSSOP-16_4.4x5mm_P0.65mm; LCSC C86803
U5: SRV05-4; SOT-23-6; LCSC C85364
U7: MAX9814; DFN-14-1EP_3x3mm_P0.4mm_EP1.78x2.35mm; LCSC C41714
U8, U9: TS5A63157DBV; SOT-23-6; LCSC C2673185
U10: LM386; SOIC-8-1EP_3.9x4.9mm_P1.27mm_EP2.41x3.3mm_ThermalVias; LCSC C383071
U13, U14: SA818S; LCSC C3001549

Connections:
+3.3VA: C13.1, L1.1, U7.5 (VDD)
+3V3: C1.1, C2.1, C3.1, C10.1, C12.1, C14.1, C37.1, C38.1, D1.2 (A), D2.2 (A), J1.1, J4.3, J5.3, L1.2, R7.2, R11.2, U2.2 (3V3), U3.2 (VO), U4.16 (VCC), U8.5 (V+), U9.5 (V+)
+5V: C4.1, C5.1, C9.1, C25.1, C26.1, C31.1, C32.1, C33.2, C34.1, FB2.2, U1.16 (VCC), U3.3 (VI), U5.5 (VP), U10.6 (V+), U13.8 (VBATT), U14.8 (VBATT)
/-SLEEP: U7.2 (~SHDN)
/AMPLIFIED_AUDIO_OUT: C28.2, J1.3
/AUDIO_IN: C27.1, J3.2, U9.4
/BASE1: Q1.1 (B), R2.1
/BASE2: Q2.1 (B), R4.2
/BIAS: C21.1, U7.12 (BIAS)
/BOOT: C11.1, Q2.3 (C), R11.1, U2.6 (IO_0)
/CG: C22.1, U7.3 (CG)
/EN: C8.1, Q1.3 (C), R7.1, SW1.1 (A), U2.35 (EN)
/GPIO_02: U2.11 (IO_2)
/GPIO_04: U2.12 (IO_4)
/GPIO_05: U2.29 (IO_5)
/GPIO_12: U2.8 (IO_12)
/GPIO_13: U2.9 (IO_13)
/GPIO_14: U2.7 (IO_14)
/GPIO_15: U2.10 (IO_15)
/GPIO_18: U2.30 (IO_18)
/GPIO_19: U2.32 (IO_19)
/HBIAS: TP6.1, U2.13 (HBIAS)
/MBIAS: TP3.1, U2.16 (MBIAS)
/MIC1N: TP1.1, U2.18 (MIC1N)
/MIC1P: TP2.1, U2.17 (MIC1P)
/MIC2N: TP4.1, U2.15 (MIC2_P)
/MIC2P: TP5.1, U2.14 (MIC2_N)
/MIC-AMP_IN: J1.6, R13.2
/MIC-DIGI_IN: J7.2
/MIC_AMPLIFIER_OUTPUT: J7.4, U7.6 (MICOUT)
/MIC_AR: J5.2, U7.9 (A/R)
/MIC_BIAS: C18.2, R13.1, R15.2, U7.13 (MICBIAS)
/MIC_EST_PTT: J1.4, JP1.2 (C)
/MIC_GAIN: J4.2, R19.2
/MIC_GAIN_pin: R19.1, U7.10 (GAIN)
/MIC_in: C18.1, U7.8 (MICIN)
/SENSOR_VN: TP9.1, U2.3 (SENSOR_VN)
/SENSOR_VP: TP8.1, U2.4 (SENSOR_VP)
/ant1: FL1.1 (IN), U13.12 (ANT)
/ant2: FL1.3 (OUT), J14.1 (In)
/ant3: FL2.1 (IN), U14.12 (ANT)
/ant4: FL2.3 (OUT), J15.1 (In)
/cc1: J6.A5 (CC1), R12.1
/cc2: J6.B5 (CC2), R14.1
/esp_audio_OUTPUT: J2.3, U8.1
/switch1: U8.6
/switch2: U9.6
/~DTR: Q2.2 (E), R2.2, U1.13 (~DTR)
/~RTS: Q1.2 (E), R4.1, U1.14 (~RTS)
AUDIO_ON1: U14.1 (Audio_ON)
AUDIO_ON2: U13.1 (Audio_ON)
AUDIO_OUT: J3.3, U9.3
D+: J6.A6 (D+), J6.B6 (D+), U1.5 (UD+), U5.1 (IO1)
D-: J6.A7 (D-), J6.B7 (D-), U1.6 (UD-), U5.6 (IO4)
GND: C1.2, C2.2, C3.2, C4.2, C5.2, C6.2, C8.2, C9.2, C10.2, C11.2, C12.2, C13.2, C14.2, C15.2, C16.2, C21.2, C22.2, C24.2, C25.2, C26.2, C30.2, C31.2, C32.2, C33.1, C34.2, C37.2, C38.2, FL1.2 (GND), FL1.4 (GND), FL2.2 (GND), FL2.4 (GND), H1.1, H2.1, H3.1, H4.1, J1.2, J1.5, J3.1, J4.1, J5.1, J6.A1 (GND), J6.A12 (GND), J6.B1 (GND), J6.B12 (GND), J7.1, J8.1 (Shield), J9.1, J14.2 (Ext), J15.2 (Ext), R5.1, R8.1, R12.2, R14.2, R16.1, R17.2, R18.2, RV1.3, SW1.2 (B), TP10.1, TP11.1, TP12.1, TP13.1, U1.1 (GND), U2.1 (GND), U2.19 (GND), U2.20 (GND), U2.38 (GND), U3.1 (GND), U4.1 (A0), U4.2 (A1), U4.3 (A2), U4.8 (GND), U5.2 (VN), U7.4 (GND), U7.7 (GND), U7.11 (GND), U7.15 (GND), U8.2 (GND), U9.1, U9.2 (GND), U10.2 (-), U10.4 (GND), U13.9 (GND), U13.10 (GND), U14.9 (GND), U14.10 (GND)
HPOUT_L: C7.1
HPOUT_R: C17.2
H/L1: U4.6 (IO_2), U14.7 (H/L)
H/L2: U4.11 (IO_6), U13.7 (H/L)
LINE_L: C19.2
LINE_R: C23.1
unnamed: C6.1, U1.4 (V3)
unnamed: C15.1, J6.S1 (SHIELD), R16.2
unnamed: C16.1, U7.1 (CT)
unnamed: C17.1, U2.28 (HPOUT_R)
unnamed: C19.1, U2.22 (LINE_INL)
unnamed: C20.1, J7.3
unnamed: C20.2, J2.1, U8.3
unnamed: C24.1, U10.7 (BYPASS)
unnamed: C27.2, RV1.1
unnamed: C28.1, R20.2, U10.5
unnamed: C29.1, U10.8 (GAIN)
unnamed: C29.2, RV2.2
unnamed: C30.1, R20.1
unnamed: D1.1 (K), R9.2
unnamed: D2.1 (K), R10.2
unnamed: D3.2 (A), J9.2
unnamed: D4.1 (K), R5.2
unnamed: JP1.1 (A), R3.2
unnamed: JP1.3 (B), R1.1
unnamed: R6.2, U1.3 (RXD)
unnamed: R15.1, R17.1, U7.14 (TH)
unnamed: RV1.2, U10.3 (+)
unnamed: RV2.1, U10.1 (GAIN)
unnamed: C23.2, U2.21 (LINE_INR)
unnamed: C7.2, U2.27 (HPOUT_L)
PD1: R8.2, U4.5 (IO_1), U4.7 (IO_3), U14.6 (PD)
PD2: R18.1, U4.10 (IO_5), U4.12 (IO_7), U13.6 (PD)
PTT1: R3.1, U4.4 (IO_0), U14.5 (PTT)
PTT2: R1.2, U4.9 (IO_4), U13.5 (PTT)
RF_AUDIO_INPUT: J2.2, U8.4
RX1: U2.34 (IO_21), U14.17 (TXD(TX))
RX2: D4.2 (A), U2.31 (IO_23), U13.17 (TXD(TX))
SCL: U4.14 (SCL)
SDA: U4.15 (SDA)
TX1: TP7.1, U2.33 (IO_22), U14.16 (RXD_(RX))
TX2: U2.5 (IO_34), U13.16 (RXD_(RX))
UART0_RX: R9.1, U1.2 (TXD), U2.37 (RXD0)
UART0_TX: R6.1, R10.1, U2.36 (TXD0)
VBUS: D3.1 (K), FB2.1, J6.A4 (VBUS), J6.A9 (VBUS), J6.B4 (VBUS), J6.B9 (VBUS)

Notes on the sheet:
3V3 LDO
MISCELANIOUS
https://lcsc.com/products/Audio-Connectors_590.html?keyword=audio%20jack
https://lcsc.com/product-detail/Audio-Power-OpAmps_HGSEMI-LM386M-1-TR_C383071.html https://lcsc.com/product-detail/Audio-Power-OpAmps_Texas-Instruments-LM386MX-1-NOPB_C23573.html
danger pins: IO_0 IO_2
https://lcsc.com/products/Variable-Resistors-Potentiometers_520.html
SA818-2
VDD: 1:2000 NC: 1:4000 GND: 1:500
SA818-1
15ms delay needed (10-20ms is fine)
MIC AMP
ANALOG BIDIRECTIONAL SWITCHES
RF MODULES
MCU+PROGRAMING
AUDIO POWER AMPLIFIER
MIC AMPLIFIER
10k & 1u
750mA max current
CONTROL
AUDIO IO
???
VDD: 40dB NC: 60dB GND: 50dB
https://lcsc.com/products/Analog-Switches-Multiplexers_618.html

Board: 4 copper layers, 131 parts (15 on the bottom side), 79 nets, no tracks yet.

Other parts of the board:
kibuzzard-63C04C05: G***; kibuzzard-63C04C05
kibuzzard-63C0517C, kibuzzard-63C0517C#2, kibuzzard-63C0517C#3, kibuzzard-63C0517C#4: G***; kibuzzard-63C0517C
kibuzzard-639A1F7F, kibuzzard-639A1F7F#2, kibuzzard-639A1F7F#3: G***; kibuzzard-639A1F7F
kibuzzard-639A1F94: G***; kibuzzard-639A1F94
kibuzzard-639A1FDB: G***; kibuzzard-639A1FDB
kibuzzard-639A1FE7: G***; kibuzzard-639A1FE7
kibuzzard-639A20B2, kibuzzard-639A20B2#2: G***; kibuzzard-639A20B2
kibuzzard-639A20C5: G***; kibuzzard-639A20C5
kibuzzard-639A25E0, kibuzzard-639A25E0#2: G***; kibuzzard-639A25E0
kibuzzard-639A26B5: G***; kibuzzard-639A26B5
kibuzzard-639A2114: G***; kibuzzard-639A2114
kibuzzard-639A2692: G***; kibuzzard-639A2692

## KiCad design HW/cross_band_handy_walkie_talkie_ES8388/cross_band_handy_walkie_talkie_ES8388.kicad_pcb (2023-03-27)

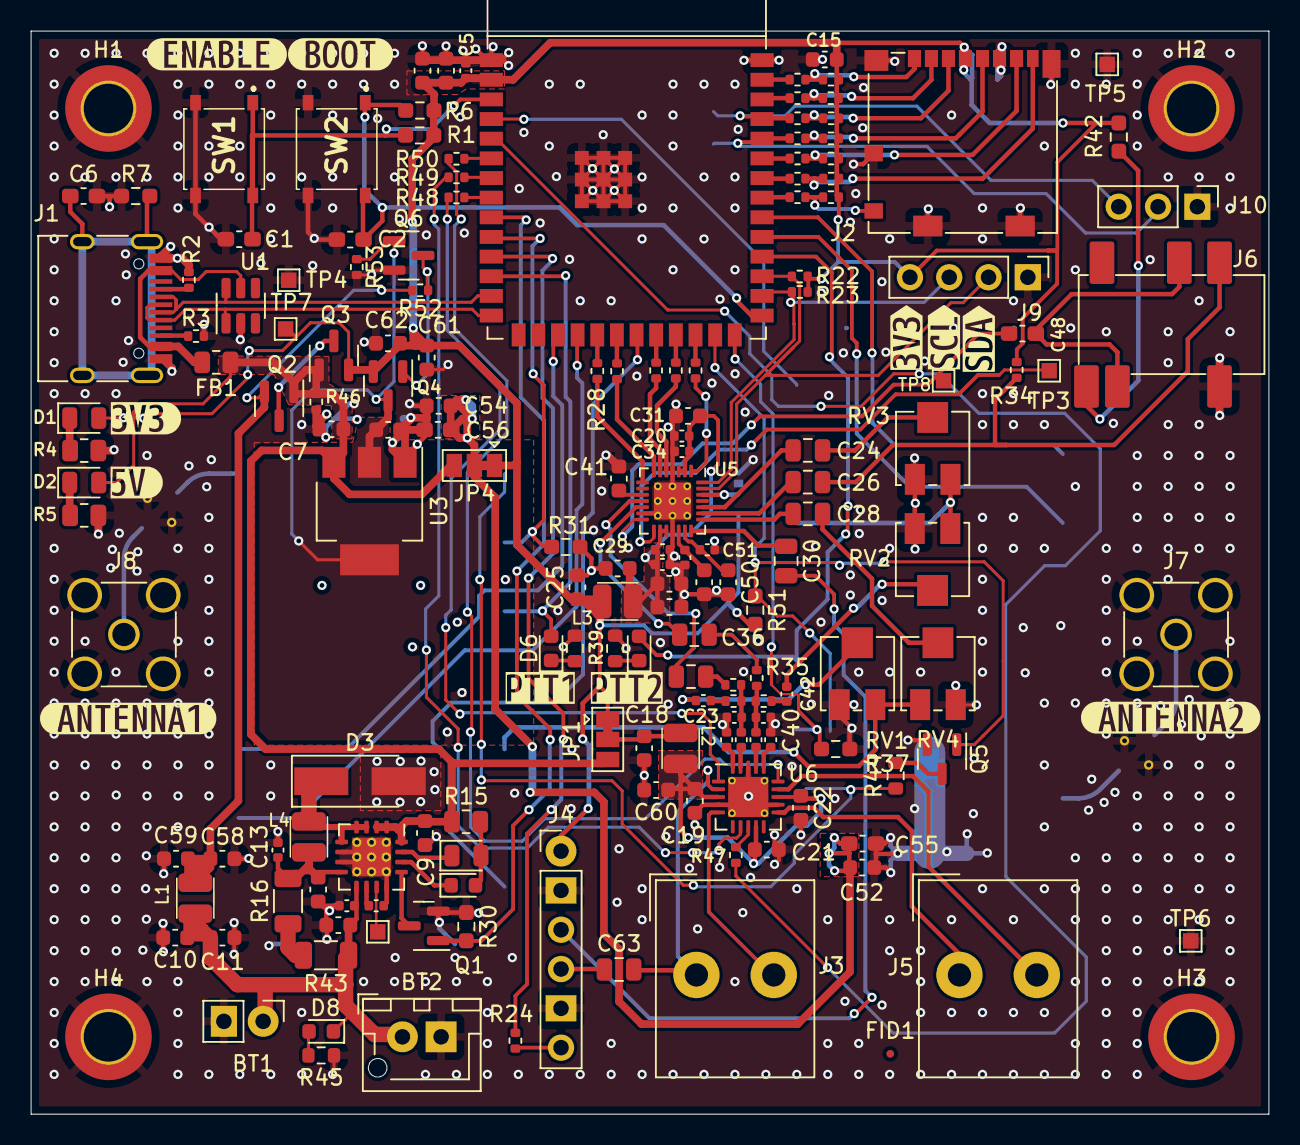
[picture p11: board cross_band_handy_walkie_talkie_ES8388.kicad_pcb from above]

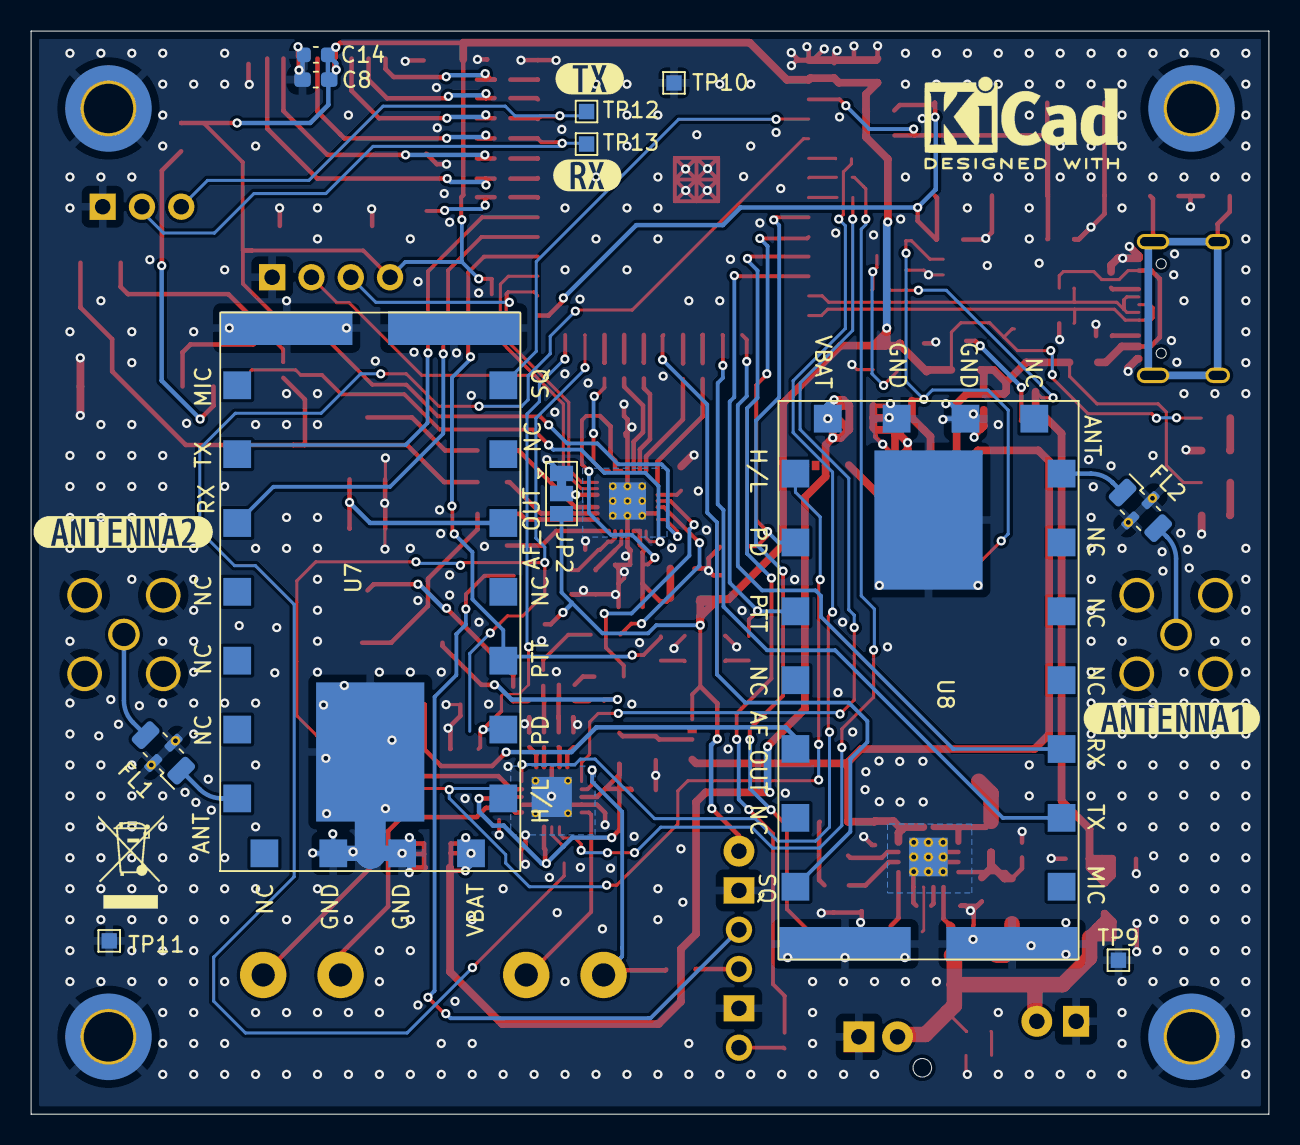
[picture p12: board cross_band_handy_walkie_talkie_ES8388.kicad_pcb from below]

Board: 4 copper layers, 80.0 x 70.0 mm, 199 parts (18 on the bottom side), 125 nets.

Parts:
BT1: Battery_Cell; PinHeader_1x02_P2.54mm_Vertical
BT2: Battery_Cell; JST_XH_B2B-XH-AM_1x02_P2.50mm_Vertical
C1, C2: 100n; C_0603_1608Metric_Pad1.08x0.95mm_HandSolder
C3, C4, C7, C9, C10, C11, C12, C14, C15, C16, C18, C19, C21, C22, C25, C29, C31, C39, C41, C44, C47, C50, C52, C54, C57, C58, C59, C60, C61, C62: 10u; C_0603_1608Metric
C5, C13, C17, C20, C23, C34, C35, C37, C38, C40, C42, C43, C45, C46, C51, C53: 1u; C_0402_1005Metric
C6: 15p; C_0603_1608Metric_Pad1.08x0.95mm_HandSolder
C8, C48, C55, C56: 1u; C_0603_1608Metric_Pad1.08x0.95mm_HandSolder
C24, C26, C28, C30, C33, C36, C63: 22u; C_0805_2012Metric
C27, C32: 4n7; C_0402_1005Metric
D1, D2, D5: green; LED_0805_2012Metric
D3: D_Schottky; D_SMA_Handsoldering
D4, D6, D7, D8: red; LED_0603_1608Metric
FB1: FerriteBead_Small; R_0805_2012Metric
FID1: Fiducial; Fiducial_0.5mm_Mask1mm
FID2: Fiducial; KiCad-Logo2_5mm_SilkScreen
FID3: Fiducial; WEEE-Logo_4.2x6mm_SilkScreen
FL1, FL2: LFCN-160; Filter_Mini-Circuits_FV1206
H1, H2, H3, H4: hole; MountingHole_3.2mm_M3_DIN965_Pad_TopBottom
J1: USB_C_Receptacle; USB_C_Receptacle_HRO_TYPE-C-31-M-12
J2: Micro_SD_Card_Det; microSD_HC_Molex_104031-0811
J3, J5: Screw_Terminal_01x02; Altech_AK300_1x02_P5.00mm_45-Degree
J4: Conn_01x06; PinHeader_1x06_P2.54mm_Vertical
J6: AudioJack4_SwitchTR1; PJ-316A-6A
J7, J8: SMA; SMA_Amphenol_901-144_Vertical
J9: Conn_01x04; PinHeader_1x04_P2.54mm_Vertical
J10: Conn_01x04; PinHeader_1x03_P2.54mm_Vertical
JP1, JP2, JP4: 3p; SolderJumper-3_P1.3mm_Bridged12_Pad1.0x1.5mm
L1, L2, L3, L4: 4u7; Inductor_2.5x2x1.2mm
Q1, Q5, Q6: nMOS; SOT-23
Q2, Q3, Q4: AO3401A; SOT-23
R1, R6, R30, R31, R37, R42, R51: 10k; R_0603_1608Metric_Pad0.98x0.95mm_HandSolder
R2, R3, R22, R23: 5k1; R_0402_1005Metric
R4, R5, R15: 1k; R_0805_2012Metric
R7: 1Meg; R_0603_1608Metric_Pad0.98x0.95mm_HandSolder
R8, R9, R10, R11, R12, R13, R21, R24, R25, R47, R48, R49, R50: 10; R_0402_1005Metric
R14, R17, R18, R19, R20, R36, R40, R46, R52, R53: 10k; R_0402_1005Metric
R16, R43: 0R1; R_1206_3216Metric
R26, R27, R28, R29: 27; R_0402_1005Metric
R32, R33, R34, R35, R41: 2k2; R_0402_1005Metric
R38, R39, R44, R45: 1k; R_0603_1608Metric
RV1, RV2, RV3, RV4: 10k; Potentiometer_Bourns_3314J_Vertical
SW1, SW2: MCU_RESET; PTS526SK15SMTR2LFS
TP2, TP3, TP4, TP5, TP6, TP7, TP8, TP9, TP10, TP11, TP12, TP13: TestPoint; TestPoint_Pad_1.0x1.0mm
U1: SRV05-4; SOT-23-6
U2: ESP32-S3-WROOM-1
U3: AMS1117-3.3; SOT-223-3_TabPin2
U4: TP5000; QFN-16-1EP_4x4mm_P0.65mm_EP2.5x2.5mm_ThermalVias
U5: ES8388; QFN-28-1EP_4x4mm_P0.4mm_EP2.4x2.4mm_ThermalVias
U6: TPA2012D2; QFN-20-1EP_4x4mm_P0.5mm_EP2.6x2.6mm_ThermalVias
U7, U8: SA818S
kibuzzard-641A07F0: G***; kibuzzard-641A07F0
kibuzzard-641A0805: G***; kibuzzard-641A0805
kibuzzard-641B449E: G***; kibuzzard-641B449E
kibuzzard-641B4493: G***; kibuzzard-641B4493
kibuzzard-641EB0C1, kibuzzard-641EB0C1#2: G***; kibuzzard-641EB0C1
kibuzzard-641EB0D1, kibuzzard-641EB0D1#2: G***; kibuzzard-641EB0D1
kibuzzard-641EB1A6: G***; kibuzzard-641EB1A6
kibuzzard-641EB1B1: G***; kibuzzard-641EB1B1
kibuzzard-641EB11F: G***; kibuzzard-641EB11F
kibuzzard-641EB058: G***; kibuzzard-641EB058
kibuzzard-641EB069: G***; kibuzzard-641EB069
kibuzzard-641EB116: G***; kibuzzard-641EB116
kibuzzard-641EB161: G***; kibuzzard-641EB161

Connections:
+3V3: C3.1, C4.1, C5.2, C8.2, C14.1, C15.1, C25.1, C61.1, C62.1, D1.2 (A), J2.4 (VDD), J4.1, J9.4, JP1.1 (A), JP2.3 (B), JP4.1 (A), L3.1, Q3.2 (S), Q4.2 (S), R1.1, R6.2, R14.2, R17.2, R18.2, R19.2, R20.2, R22.1, R23.1, R34.1, R36.2, R40.2, R42.1, R51.2, TP7.1, U2.2 (3V3)
+5V: C7.1, C9.1, D2.2 (A), FB1.1, JP1.3 (B), JP4.3 (B), Q2.1 (G), Q3.1 (G), R15.1, R46.2, U3.3 (VI), U4.1 (VIN), U4.2 (VIN), U4.16 (VIN)
+BATT: BT1.1 (+), BT2.1 (+), C10.1, C11.1, C16.1, C17.2, D8.1 (K), L1.1, R43.1, U4.9 (BAT)
/Audio_Codec/3V33: C20.2, C29.1, C31.1, C34.2, C39.1, C43.1, C44.1, C45.2, L3.2, U5.2 (DVDD), U5.3 (PVDD), U5.16 (HPVDD), U5.17 (AVDD)
/Audio_Codec/A_audio_1: C24.1, U5.24 (LIN1)
/Audio_Codec/A_audio_2: C26.1, U5.23 (RIN1)
/Audio_Codec/A_audio_3: C28.1, U5.22 (LIN2)
/Audio_Codec/A_audio_4: C30.1, U5.21 (RIN2)
/Audio_Codec/BCLK: R27.2, U5.5 (SCLK)
/Audio_Codec/DIN: R29.2, U5.6 (DSDIN)
/Audio_Codec/DOUT: R28.2, U5.8 (ASDOUT)
/Audio_Codec/JACK_DETECT: J6.TN, R42.2
/Audio_Codec/Jack_MIC_INPUT_1: C26.2, J6.S, R34.2
/Audio_Codec/L_out1_: C36.2, U5.12 (LOUT1)
/Audio_Codec/MCLK: R25.2, U5.1 (MCLK)
/Audio_Codec/MIC_INPUT_2: C30.2, J4.3
/Audio_Codec/Power_amp_Vcc: C19.1, C21.1, C22.1, C60.1, L2.2, U6.3 (PVDD), U6.9 (AVDD), U6.13 (PVDD)
/Audio_Codec/Power_amp_Vcc_intermediate: C18.1, JP1.2 (C), L2.1
/Audio_Codec/R_out1_: C33.2, U5.11 (ROUT1)
/Audio_Codec/Speaker_L+: C63.2, J3.1, U6.2 (OUTL+)
/Audio_Codec/Speaker_L-: J3.2, U6.5 (OUTL-)
/Audio_Codec/Speaker_R+: J5.2, U6.14 (OUTR+)
/Audio_Codec/Speaker_R-: J5.1, U6.11 (OUTR-)
/Audio_Codec/WCLK: R26.2, U5.7 (LRCK)
/Audio_Codec/ant1: FL1.1 (IN), U7.12 (ANT)
/Audio_Codec/ant2: FL1.3 (OUT), J7.1 (In)
/Audio_Codec/ant3: FL2.1 (IN), U8.12 (ANT)
/Audio_Codec/ant4: FL2.3 (OUT), J8.1 (In)
/BATT_filtered: C58.1, C59.1, L1.2, Q2.2 (S), R52.2
/CARD_DETECT: J2.10 (DET_A), R21.1, R40.1
/CLK: J2.5 (CLK), R13.1, R36.1
/CMD: J2.3 (CMD), R12.1, R20.1
/CS: Q1.3 (D), U4.13 (CS)
/DATA_0: J2.7 (DAT0), R8.1, R14.1
/DATA_1: J2.8 (DAT1), R9.1, R17.1
/DATA_2: J2.1 (DAT2), R10.1, R18.1
/DATA_3: J2.2 (DAT3/CD), R11.1, R19.1
/ESP_BOOT: C2.1, R6.1, SW2.1 (A), U2.27 (GPIO0/BOOT)
/ESP_EN: C1.2, R1.2, SW1.1 (A), U2.3 (EN)
/RAW_3v3: C57.1, Q4.3 (D), Q6.1 (G), R53.1, U3.2 (VO)
/buck_out: D3.1 (K), L4.1, U4.3 (LX), U4.4 (LX), U4.5 (LX)
/cc1: J1.A5 (CC1), R2.1
/cc2: J1.B5 (CC2), R3.1
AMP_L: R49.1, U6.7 (~SDL)
AMP_R: R47.1, U6.8 (~SDR)
AUDIO_ON1: U2.21 (GPIO13/TOUCH13/ADC2_CH2/FSPIQ/FSPIIO7/S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), U8.1 (Audio_ON)
AUDIO_ON2: U2.4 (GPIO4/TOUCH4/ADC1_CH3), U7.1 (Audio_ON)
D+: J1.A6 (D+), J1.B6 (D+), U1.1 (IO1), U2.14 (GPIO20/U1CTS/ADC2_CH9/CLK_OUT1/USB_D+)
D-: J1.A7 (D-), J1.B7 (D-), U1.6 (IO4), U2.13 (GPIO19/U1RTS/ADC2_CH8/CLK_OUT2/USB_D-)
G0: R50.1, U6.15 (G0)
G1: R48.1, U6.1 (G1)
GND: BT1.2 (-), BT2.2 (-), C1.1, C2.2, C3.2, C4.2, C5.1, C6.2, C7.2, C8.1, C9.2, C10.2, C11.2, C12.2, C13.1, C14.2, C15.2, C16.2, C17.1, C18.2, C19.2, C20.1, C21.2, C22.2, C25.2, C27.2, C29.2, C31.2, C32.2, C34.1, C37.1, C39.2, C40.1, C41.2, C43.2, C44.2, C45.1, C46.2, C47.2, C50.2, C51.1, C52.2, C53.1, C54.2, C55.1, C56.2, C57.2, C58.2, C59.2, C60.2, C61.2, C62.2, D3.2 (A), FL1.2 (GND), FL1.4 (GND), FL2.2 (GND), FL2.4 (GND), H1.1, H2.1, H3.1, H4.1, J1.A1 (GND), J1.A12 (GND), J1.B1 (GND), J1.B12 (GND), J2.6 (VSS), J2.9 (DET_B), J2.11 (SHIELD), J4.2, J4.5, J6.R2, J7.2 (Ext), J8.2 (Ext), J9.1, J10.1, JP2.1 (A), Q1.2 (S), Q5.2 (S), Q6.2 (S), R2.2, R3.2, R4.2, R5.2, R7.1, R30.1, R31.1, R37.2, R38.2, R39.2, R45.1, R46.1, R53.2, RV1.1, RV2.3, RV3.1, RV4.3, SW1.2 (B), SW2.2 (B), TP4.1, TP5.1, TP6.1, TP9.1, TP10.1, TP11.1, U1.2 (VN), U2.1 (GND), U2.40 (GND), U2.41 (GND), U3.1 (GND), U4.6 (GND), U4.7 (GND), U4.12 (RTRICK), U4.17 (PAD), U5.4 (DGND), U5.13 (HPGND), U5.18 (AGND), U5.29 (EP), U6.4 (PGND), U6.12 (PGND), U6.18 (AGND), U6.21 (PAD), U7.9 (GND), U7.10 (GND), U8.9 (GND), U8.10 (GND)
GPIO_1: R10.2, U2.39 (GPIO1/TOUCH1/ADC1_CH0)
GPIO_2: R11.2, U2.38 (GPIO2/TOUCH2/ADC1_CH1)
GPIO_5: R47.2, U2.5 (GPIO5/TOUCH5/ADC1_CH4)
GPIO_6: R50.2, U2.6 (GPIO6/TOUCH6/ADC1_CH5)
GPIO_7: R49.2, U2.7 (GPIO7/TOUCH7/ADC1_CH6)
GPIO_8: D6.2 (A), U2.12 (GPIO8/TOUCH8/ADC1_CH7/SUBSPICS1), U8.5 (PTT)
GPIO_9: U2.17 (GPIO9/TOUCH9/ADC1_CH8/FSPIHD/SUBSPIHD), U8.16 (RXD_(RX))
GPIO_10: U2.18 (GPIO10/TOUCH10/ADC1_CH9/FSPICS0/FSPIIO4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), U8.17 (TXD(TX))
GPIO_11: R28.1, U2.19 (GPIO11/TOUCH11/ADC2_CH0/FSPID/FSPIIO5/S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)
GPIO_12: R26.1, U2.20 (GPIO12/TOUCH12/ADC2_CH1/FSPICLK/FSPIIO6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)
GPIO_14: R29.1, U2.22 (GPIO14/TOUCH14/ADC2_CH3/FSPIWP/FSPIDQS/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)
GPIO_15: R48.2, U2.8 (GPIO15/U0RTS/ADC2_CH4/XTAL_32K_P)
GPIO_16: Q1.1 (G), R30.2, U2.9 (GPIO16/U0CTS/ADC2_CH5/XTAL_32K_NH5)
GPIO_17: R31.2, U2.10 (GPIO17/U1TXD/ADC2_CH6), U8.6 (PD)
GPIO_18: R24.2, U2.11 (GPIO18/U1RXD/ADC2_CH7/CLK_OUT3)
GPIO_21: R27.1, U2.23 (GPIO21)
GPIO_35: J9.3, R23.2, U2.28 (SPIIO6/GPIO35/FSPID/SUBSPID), U5.28 (CCLK)
GPIO_36: J9.2, R22.2, U2.29 (SPIIO7/GPIO36/FSPICLK/SUBSPICLK), U5.27 (CDATA)
GPIO_37: D7.2 (A), U2.30 (SPIDQS/GPIO37/FSPIQ/SUBSPIQ), U7.5 (PTT)
GPIO_38: U2.31 (GPIO38/FSPIWP/SUBSPIWP), U7.16 (RXD_(RX))
GPIO_39: U2.32 (MTCK/GPIO39/CLK_OUT3/SUBSPICS1), U7.17 (TXD(TX))
GPIO_40: R21.2, U2.33 (MTDO/GPIO40/CLK_OUT2)
GPIO_41: R9.2, U2.34 (MTDI/GPIO41/CLK_OUT1)
GPIO_42: R8.2, U2.35 (MTMS/GPIO42)
GPIO_43: J10.3, R12.2, TP12.1, U2.37 (U0TXD/GPIO43/CLK_OUT1)
GPIO_44: J10.2, R13.2, TP13.1, U2.36 (U0RXD/GPIO44/CLK_OUT2)
GPIO_45: R37.1, U2.26 (GPIO45), U7.6 (PD)
GPIO_47: R25.1, U2.24 (GPIO47/SPICLK_P/SUBSPICLK_P_DIFF)
GPIO_48: Q5.1 (G), R51.1, U2.25 (GPIO48/SPICLK_N/SUBSPICLK_N_DIFF)
H/L1: R44.1, U7.7 (H/L), U8.7 (H/L)
LINE_IN1: C28.2, RV4.2
LINE_IN2: C24.2, RV3.2
L_out1: C36.1, R35.1
unnamed: C6.1, J1.S1 (SHIELD), R7.2
unnamed: C12.1, C13.2, L4.2, R16.2, U4.8 (VS)
unnamed: C23.1, RV1.2
unnamed: C23.2, R32.1
unnamed: C27.1, C35.1, R32.2, R33.2
unnamed: C32.1, C38.1, R35.2, R41.1
unnamed: C35.2, U6.19 (INL-)
unnamed: C37.2, U6.20 (INL+)
unnamed: C38.2, U6.17 (INR-)
unnamed: C40.2, U6.16 (INR+)
unnamed: C41.1, U5.10 (VREF)
unnamed: C42.1, R41.2
unnamed: C42.2, RV2.2
unnamed: C46.1, C47.1, U5.19 (ADCVREF)
unnamed: C48.1, J6.R1, J6.T
unnamed: C48.2, TP8.1, U5.14 (ROUT2)
unnamed: C50.1, C51.2, U5.20 (VMID)
unnamed: C53.2, U4.10 (VREG)
unnamed: C63.1, J4.4
unnamed: D1.1 (K), R4.1
unnamed: D2.1 (K), R5.1
unnamed: D4.1 (K), U4.14 (~CHRG)
unnamed: D4.2 (A), D5.2 (A), R15.2
unnamed: D5.1 (K), U4.15 (~STDBY)
unnamed: D6.1 (K), R38.1
unnamed: D7.1 (K), R39.1
unnamed: D8.2 (A), R45.2
unnamed: JP2.2 (C), U5.26 (CE)
unnamed: Q2.3 (D), Q3.3 (D)
unnamed: Q4.1 (G), Q6.3 (D), R52.1
unnamed: Q5.3 (D), R44.2
unnamed: R16.1, R43.2
unnamed: TP2.1, U4.11 (TS)
unnamed: TP3.1, U5.15 (LOUT2)
PTT3: J4.6, R24.1
RF_power_bus: C52.1, C54.1, C55.2, C56.1, JP4.2 (C), U7.8 (VBATT), U8.8 (VBATT)
R_out1: C33.1, R33.1
Tranceiver_Audio_OUT_1: RV1.3, RV4.1, U8.3 (AF(Audio_OUT))
Tranceiver_Audio_OUT_2: RV2.1, RV3.3, U7.3 (AF(Audio_OUT))
VBUS: FB1.2, J1.A4 (VBUS), J1.A9 (VBUS), J1.B4 (VBUS), J1.B9 (VBUS), U1.5 (VP)

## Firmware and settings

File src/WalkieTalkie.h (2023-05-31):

// dummy header file: w/o this the example are not showing up
#pragma once
#include "AudioLibs/AudioKit.h"
#include "AudioTools.h"

/**
 * @brief Some additonal functionality using the custom pins which is not
 * convered by the AudioKit.
 * @author Phil Schatzmann
 * @copyright GPLv3
 */

class WalkieTalkie {
 public:
  WalkieTalkie() {
    pinMode(5, OUTPUT);
    pinMode(7, OUTPUT);
    pinMode(15, OUTPUT);
    pinMode(6, OUTPUT);
  }

  // @brief setup amplifier and gain pins
  // GPIO 5 and 7 can be used to switch the Amp on/off with a digitalWrite()
  // (low is off, high is on) GPIO 15 and 6 can be used to regulate the volume
  // with the help of an anlogWrite() on analog pins. To get max volume I could
  // also do a digitalWrite(HIGH)
  void setupAmplifier(bool leftOn = true, bool rightOn = true,
                      bool leftGain = true, bool rightGain = true) {
    //  switch left amp on
    digitalWrite(5, leftOn);
    //  switch right amp on
    digitalWrite(7, rightOn);
    // set left gain
    digitalWrite(15, leftGain);
    // set right gain
    digitalWrite(6, rightGain);
  }

  /**
   * @brief Setup pins if you use the AudioKitStream class
   */
  void setupPins(AudioKitStreamConfig &config) {
    config.sd_active = false;
    config.default_actions_active = false;
    // i2c
    config.pins.i2c_sda = 36;
    config.pins.i2c_scl = 35;
    //  i2s
    config.pin_mck = 47;
    config.pin_bck = 21;
    config.pin_ws = 12;
    config.pin_data = 14;
    config.pin_data_rx = 11;
    // sd
    config.pins.sd_cs = 2;
    config.pins.sd_miso = 42;
    config.pins.sd_mosi = 43;
    config.pins.sd_clk = 44;
  }
};

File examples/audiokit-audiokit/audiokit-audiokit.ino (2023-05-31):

/**
 * @file streams-audiokit-audiokit.ino
 * @brief Copies the audio form the input (microphone) to the output (earphones)
   Using:
- - https://github.com/pschatzmann/arduino-audio-tools
- - https://github.com/pschatzmann/arduino-audiokit 
 * @author Phil Schatzmann
 * @copyright GPLv3
 */

#include "AudioTools.h"
#include "AudioLibs/AudioKit.h"

AudioInfo info(32000, 2, 16);
AudioKitStream kit;           // Access I2S as stream
StreamCopy copier(kit, kit);  // copy kit to kit

// Arduino Setup
void setup(void) {
  Serial.begin(115200);
  AudioLogger::instance().begin(Serial, AudioLogger::Warning);

  auto config = kit.defaultConfig(RXTX_MODE);
  config.copyFrom(info);
  config.input_device = AUDIO_HAL_ADC_INPUT_LINE1; // AUX mic 
  config.output_device = AUDIO_HAL_DAC_OUTPUT_ALL; // AUDIO_HAL_DAC_OUTPUT_ALL, AUDIO_HAL_DAC_OUTPUT_LINE1, AUDIO_HAL_DAC_OUTPUT_LINE2
  config.sd_active = false;
  config.default_actions_active = false;
  // i2c
  config.pins.i2c_sda = 36;
  config.pins.i2c_scl = 35;
  //  i2s
  config.pin_mck = 47;
  config.pin_bck = 21;
  config.pin_ws = 12;
  config.pin_data = 14;
  config.pin_data_rx = 11;
  kit.begin(config);
  kit.setVolume(1.0); // max volume

}

// Arduino loop - copy data
void loop() { copier.copy(); }
